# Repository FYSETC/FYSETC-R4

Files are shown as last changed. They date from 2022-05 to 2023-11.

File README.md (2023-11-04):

# FYSETC_R4

## Hardware

All related hardware files are in `hardware` folder in this repository.

## Firmware

FYSETC R4 only support Klipper firmware. All related Klipper firmware files like `printer.cfg` are in `firmware` folder in this repository.

### Klipper Compile options

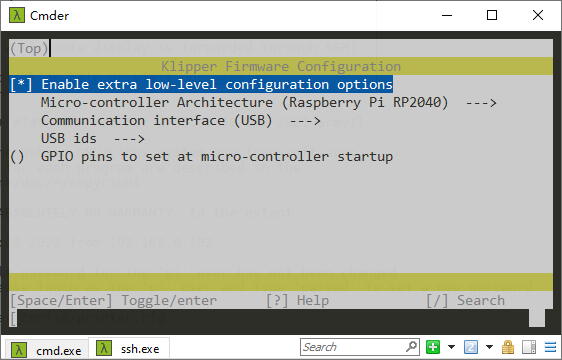
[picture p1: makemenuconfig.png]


### Firmware upload

Step 1: Power on the board

Step 2: Connect R4 to your computer with USBC cable

Step 3: Push an hold `BOOTSEL` button

Step 4: Click `RST` button and release `BOOTSEL` button

Step 5: `RPI-RP2` folder will show up on your computer, copy your built firmware `klipper.uf2` to the folder.

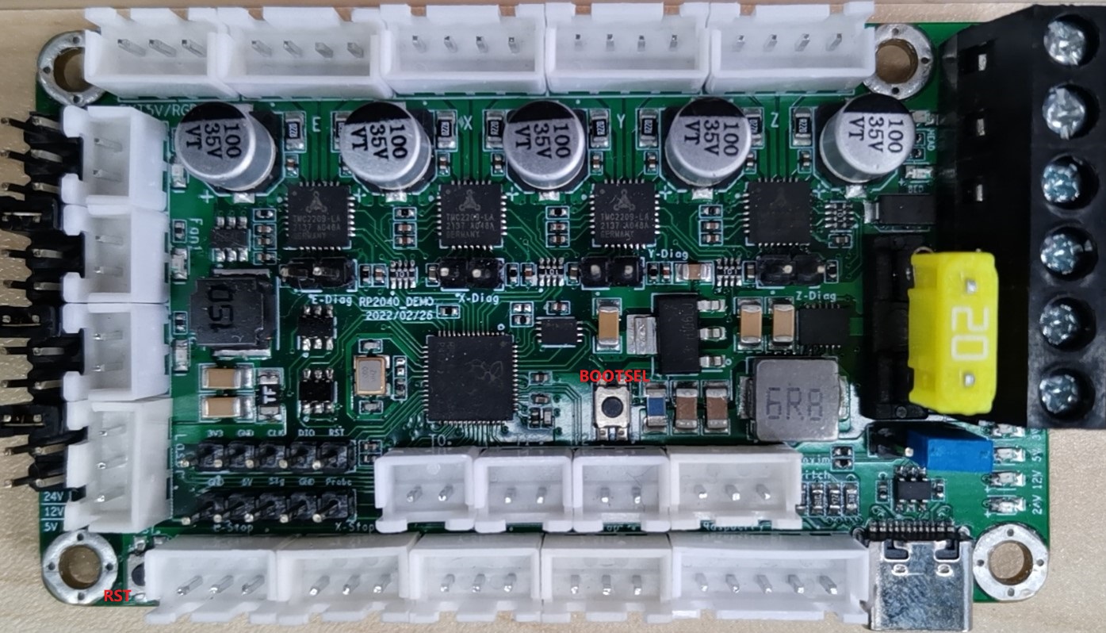
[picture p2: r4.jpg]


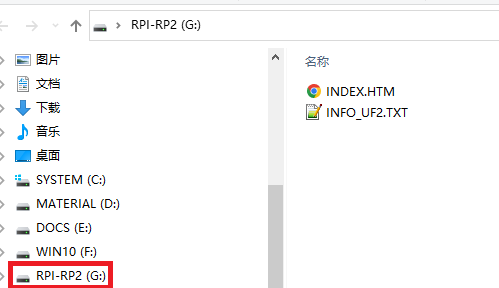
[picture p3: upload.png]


### Configuration

See `printer.cfg` in this repository `firmware` folder.

### Pinout



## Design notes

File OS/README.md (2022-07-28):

# OS

## SAMFi-OS_OrangePi_zero

Before you config the [SAMF-OS_OrangePi_zero](https://github.com/FYSETC/FYSETC-SAMFi-OS). You need an TF card with at least 8G capacity.

### Step 1

Download and flash the OS image with `balenaEtcher` software to your TF card. Insert your flashed TF card to OrangePi-zero and connect Ethernet cable then power on. Find the ip address of OrangePi-zero on your router, host name is `orangepizero`.

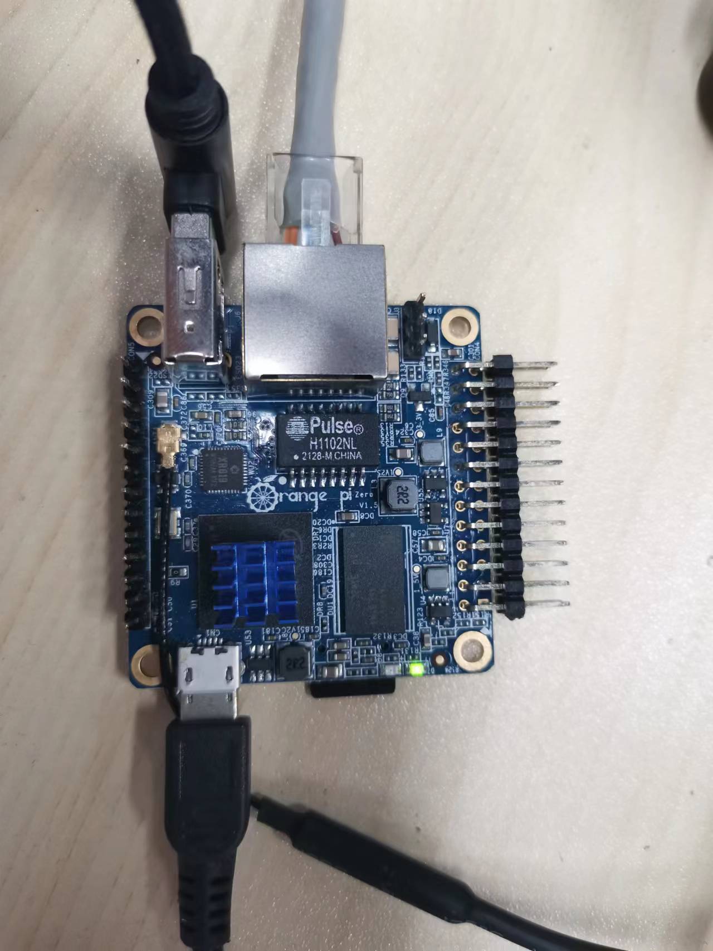
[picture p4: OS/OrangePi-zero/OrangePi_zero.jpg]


### Step 2

You can find the firmware `klipper.uf2` in `OrangePi-zero` folder after you download the github repository. It is also stay in the OS path `firmwares\r4.bin` after you login the OS with SSH.

Original SSH account and password:

```
account: fysetc
password: fysetc123
```

follow the instructions [here](https://github.com/FYSETC/FYSETC-R4#firmware-upload) for firmware uploading. 

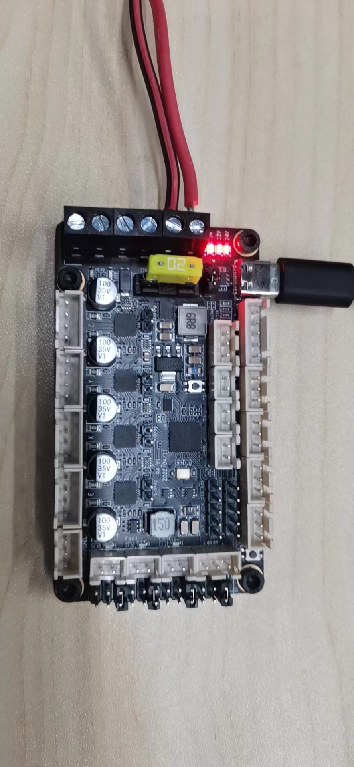
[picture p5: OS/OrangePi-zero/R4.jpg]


### Step 3:

Prepare the `pinter.cfg`, using the command below

```
cp klipper_config/r4.cfg firmwares/printer.cfg
```

You probably need to change `id` by `ls /dev/serial/by-id` command.

I use the generic Klipper config for this example, you need to change it according to your machine. Now visit the webpage with your orangepi-zero IP address. Good to go.

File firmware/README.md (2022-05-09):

# firmware

FYSETC R4 only support Klipper firmware.

## printer.cfg

`printer.cfg` is an example configuration for VORON v0.

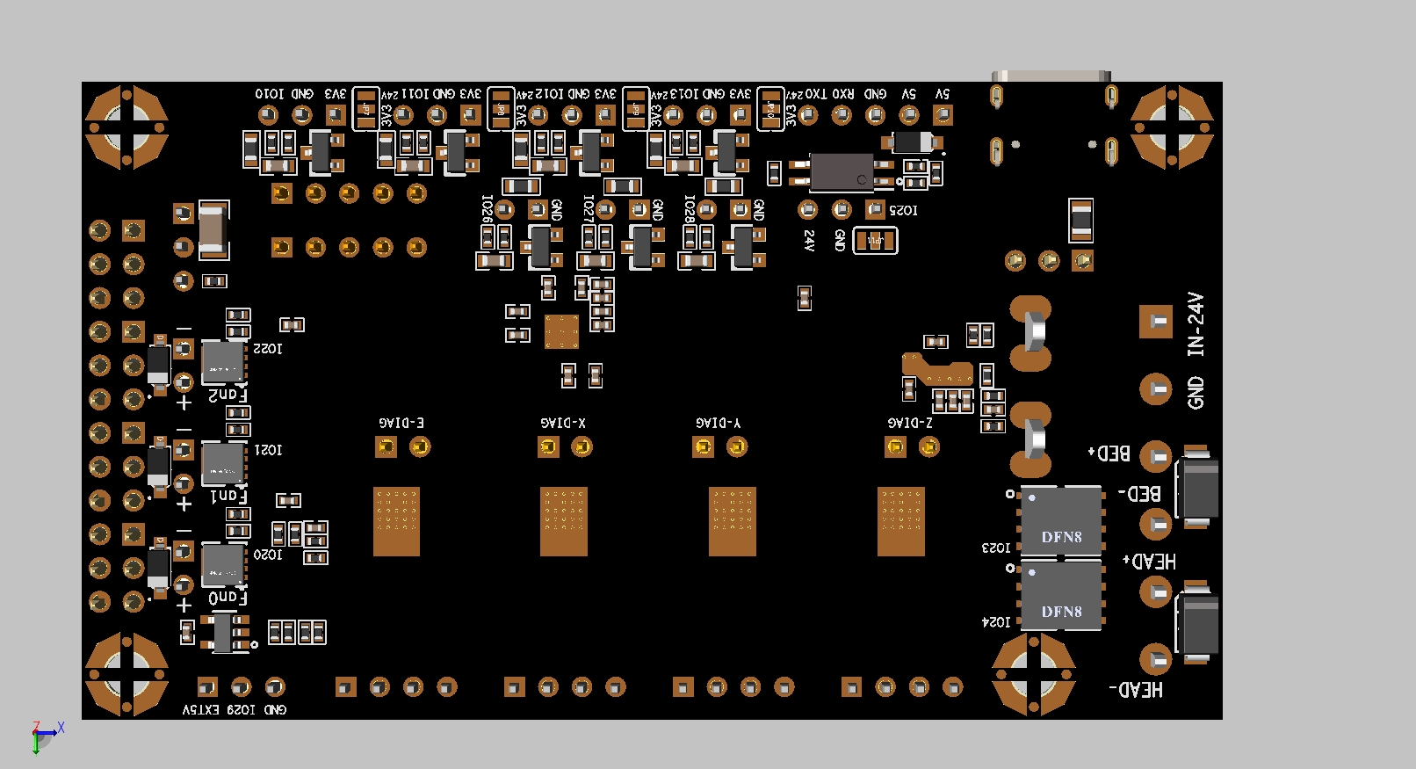
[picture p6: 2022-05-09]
hardware/R4_BOTTOM.jpeg

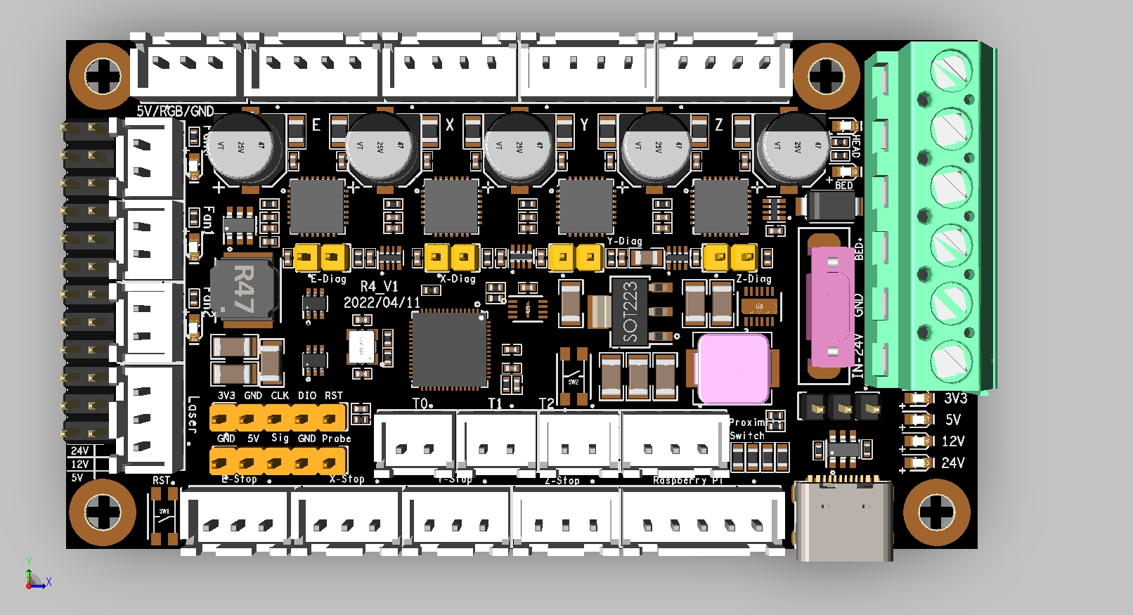
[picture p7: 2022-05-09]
hardware/R4_TOP.jpeg

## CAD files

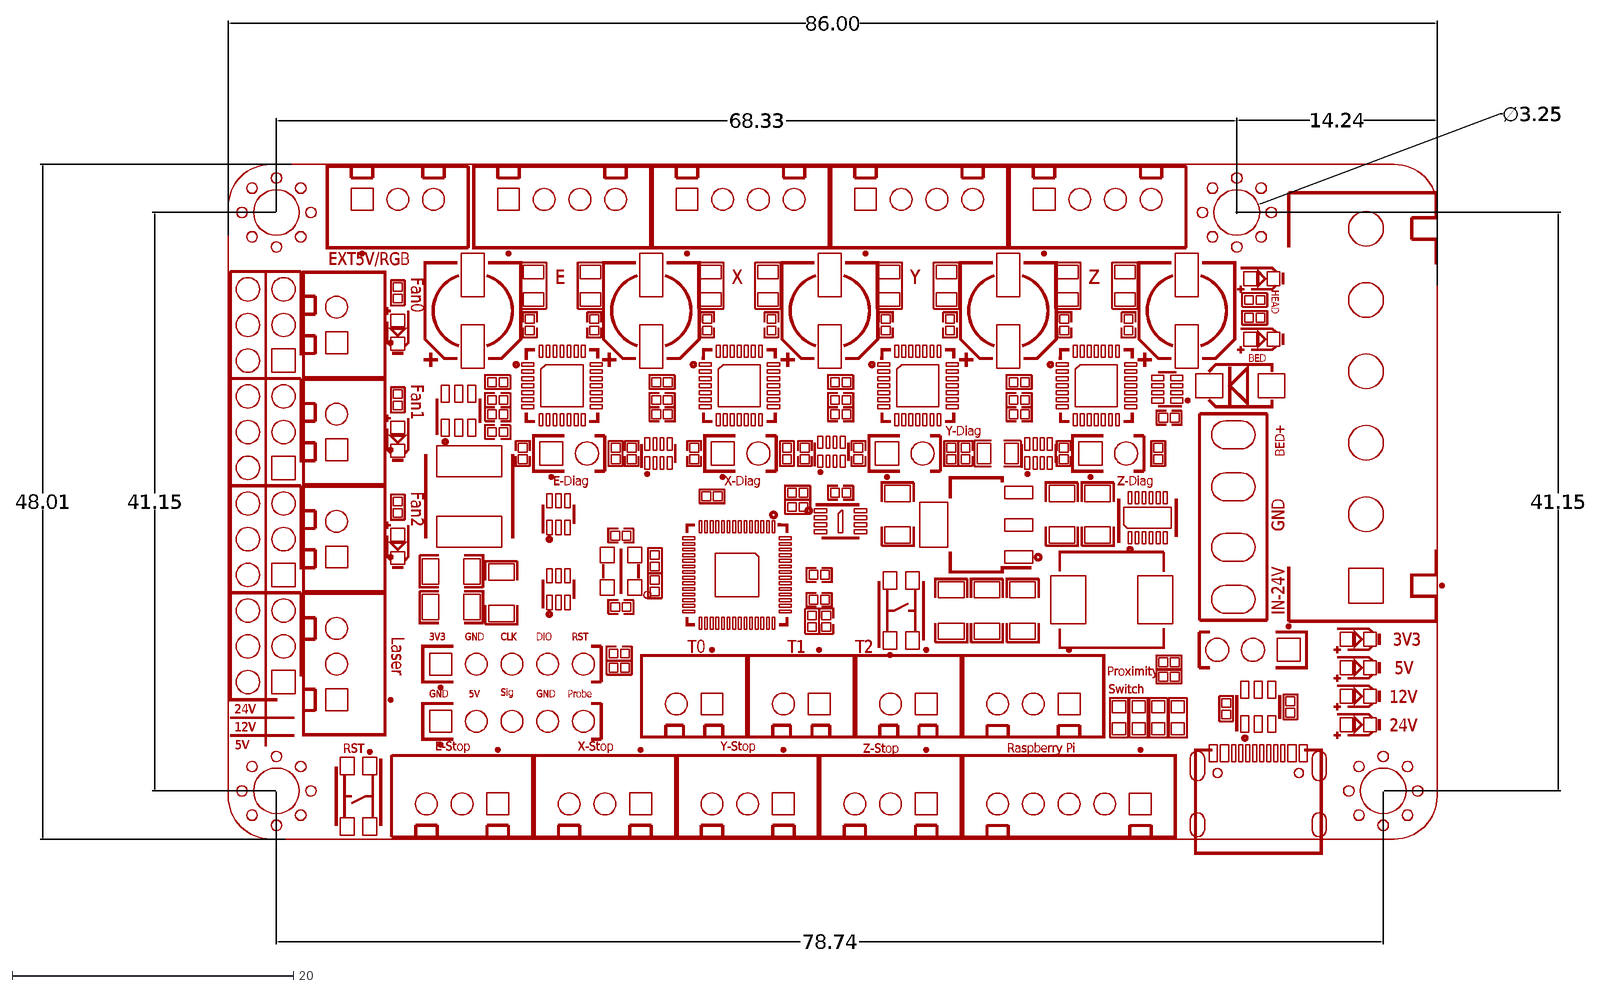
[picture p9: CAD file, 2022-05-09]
hardware/R4_V1_CAD.dxf
Z-Diag
Y-Diag
X-Diag
E-Diag
BED+
GND
IN-24V
Switch
Proximity
Laser
Probe
Sig
5V
BED
HEAD
EXT5V/RGB
12V
24V
RST
T2
T1
T0
DIO
CLK
3V3
Raspberry Pi
Z-Stop
Y-Stop
X-Stop
E-Stop
Fan2
Fan1
Fan0
Z
Y
E
X
14.24
68.33
86.00
41.15
48.01
78.74
∅3.25

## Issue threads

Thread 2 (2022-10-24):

MCU does not start

mmarub, 2022-10-24:
Hello.
I have orange pi lite(armrbian Armbian 22.08.2 Bullseye) and Fysetc R4 with firmware( v0.10.0-613-gebc3b0de).
At startup, the klipper does not see the MCU,  until I press the button RST on MCU.
Why is this happening? the board is inside the printer and it is inconvenient to press the RST button every time.

3DSmitty, 2025-05-04:
Same thing is happening to me.

3DSmitty, 2025-05-05:
I used the flash_nuke method to wipe / reset the pico and then loaded the klipper.uf2 from here and it seems to be working now.

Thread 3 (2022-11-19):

Pinout

TinkerBridget, 2022-11-19:
Hi, can we get a full pinout pic for this board?

I got sent one for free, and I really want to use it, but it doesn't have a full pinout like the spider does so I can't really hook it up without risking killing components or the board.

bistory, 2022-11-26:
👍 I would need it too, especially for laser port and the headers (clk, dio, rst, sig, probe) near the e-stop plug.

dadoblu2000, 2024-12-20:
I have a servo to control where can I connect it on the board?

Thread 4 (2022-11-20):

sensorless homing

freasy, 2022-11-20:
I cant get sensorless homing to work.
What ever configuration i do, it doesnt work. different ^, ~, ! setups, does only change if it does nothing (not moving) or not stopping.
If i change the sense register, it doesnt change the behaviour at all.

mmarub, 2023-01-06:
try to close pins on board, near to XY drivers

zedic, 2023-01-31:
I can **not** get Sensorless Homing to work either.  I have a jumper on X-Diag JP4 and Y-Diag JP5.  I have followed the directions at https://www.klipper3d.org/TMC_Drivers.html#configure-printercfg-for-sensorless-homing

SET_TMC_FIELD STEPPER=stepper_x FIELD=SGTHRS VALUE=255
G28 X0

This causes the stepper to crash into end stop and bang repeatedly. It does not stop. I have tried various homing speeds and SGTHRS values .  No luck.

Here is my config.
```
[stepper_x]
step_pin: gpio3
dir_pin: gpio2
enable_pin: !gpio4
rotation_distance: 40
microsteps: 32
full_steps_per_rotation:
endstop_pin: tmc2209_stepper_x:virtual_endstop
position_endstop: 0
position_max: 235
homing_speed: 20
homing_retract_dist: 0

[tmc2209 stepper_x]
uart_pin: gpio9
tx_pin: gpio8
uart_address: 0
interpolate: False
run_current: 0.8
sense_resistor: 0.110
stealthchop_threshold: 0
diag_pin: ^gpio11
driver_SGTHRS: 255
```

GerogeFu, 2023-02-02:
The point to enable the sensorless feature have 3 key parameters(run_current, hold_current and driver_SGTHRS) need to adjust
```
run_current: 1.2
hold_current: 1
stealthchop_threshold: 999999
diag_pin: ^gpiox
driver_SGTHRS: 20 #100
 ```

It is part of the config

The current need to be big enough to have the motor bump effect, but can't be too big or it won't work too
driver_SGTHRS is related to the load
The three parameter need to have the most effective combination to make sensorless homing work, it take me days to make it work too

And the config homing_retract_dist in [stepper_x] section  need to set to 0

Actually, i don't want to enable this feature, it is not that reliable

zedic, 2023-02-02:
FYI: The Klipper documentation (https://www.klipper3d.org/TMC_Drivers.html) states when setting up sensorless homing: **"Be sure that a hold_current setting is not specified in the TMC driver section of the config."** and they also recommend using "spreadCycle" with microsteps instead of steatlhchop.  But I tried these new settings anyway, and they still did not work for me.  The stepper does not stop.  The end stop pin is never tripped.  I used (diag_pin: ^gpio11) not (diag_pin: ^gpiox).  I'm guessing your using board_pins aliases but that is not shown in the config.

GerogeFu, 2023-02-03:
It is piece of the config, gpiox represent gpio you want to set.

aeresov, 2023-03-24:
I confirm it doesn't work for me either

BluesCoderRepo, 2023-05-11:
Someone solved this problem.(DIY세상 in Korea Kakao Talk Open Chat Room)
The problem is the value of uart_address.
extruder : 0
x: 1
y: 2
z: 3
That's it.

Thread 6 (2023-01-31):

BLTouch not working

zedic, 2023-01-31:
I can not get BLTouch 3.1 working with R4. I have tried two different BLTouch.

I am using these settings:

[stepper_z]
step_pin: gpio19
dir_pin: !gpio18
enable_pin: !gpio17
endstop_pin: probe:z_virtual_endstop  # Use BLTouch

[bltouch]
sensor_pin: gpio13 # White Wire
control_pin: gpio25 # Yellow Wire

The BLTouch does not respond to BLTOUCH_DEBUG COMMAND=pin_up or BLTOUCH_DEBUG COMMAND=pin_down

Attached is a picture of my BLTouch Wiring.
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

zedic, 2023-01-31:
I got the BLTouch working. I put the yellow wire on J32-Pin5 (gpio25) and I moved the signal pin to the z_stop (gpio13).  I checked the schematic and I believe  J32-Pin3 is supposed to be the same as z_stop (gpio13), but it does not seem to work.  I tested J32 pins with a multimeter, and none of those pins have continuity with z_stop.  There seems to be a problem with my board, or bad schematics.

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

I also have not been able to get  Sensorless Homing to work.  This board needs better documentation.

zedic, 2023-01-31:
I got it working using the Z-Stop (J23 - Pin 3.) as shown in the picture.
I believe my issue is related to the circuit.  The Z-stop J23 - Pin 3 circuit has a 10K pull down resistor, but BL-Touch J32 - Pin 3 circuit seems to be connected to RPI GPIO13 in some different way.  When the bltouch is connected to J32 - Pin3 I used the commands BLTOUCH_DEBUG COMMAND=pin_down, BLTOUCH_DEBUG COMMAND=touch_mode, QUERY_PROBE which does **not** result in **tiggered**, but it is tiggered correctly when connected to Z-Stop.  There might be a way to get this working, but I could not figure it out.

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

GerogeFu, 2023-02-02:
I test it on my side it is working, maybe it is related to the config https://www.klipper3d.org/BLTouch.html#bl-touch-v3 , pic is my wiring
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

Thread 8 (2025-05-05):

Klipper Update

3DSmitty, 2025-05-05:
Trying to update klipper firmware on the R4 as the one supplied here is versions behind. Klipper menuconfig it has changed a lot for the RP2040. I tried these options:

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

but it causes the pi to hang and klipper doesn't even start. What should these new options be set to?

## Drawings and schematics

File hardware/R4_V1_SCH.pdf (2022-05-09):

5 | 4 | 3 | 2 | 1

D

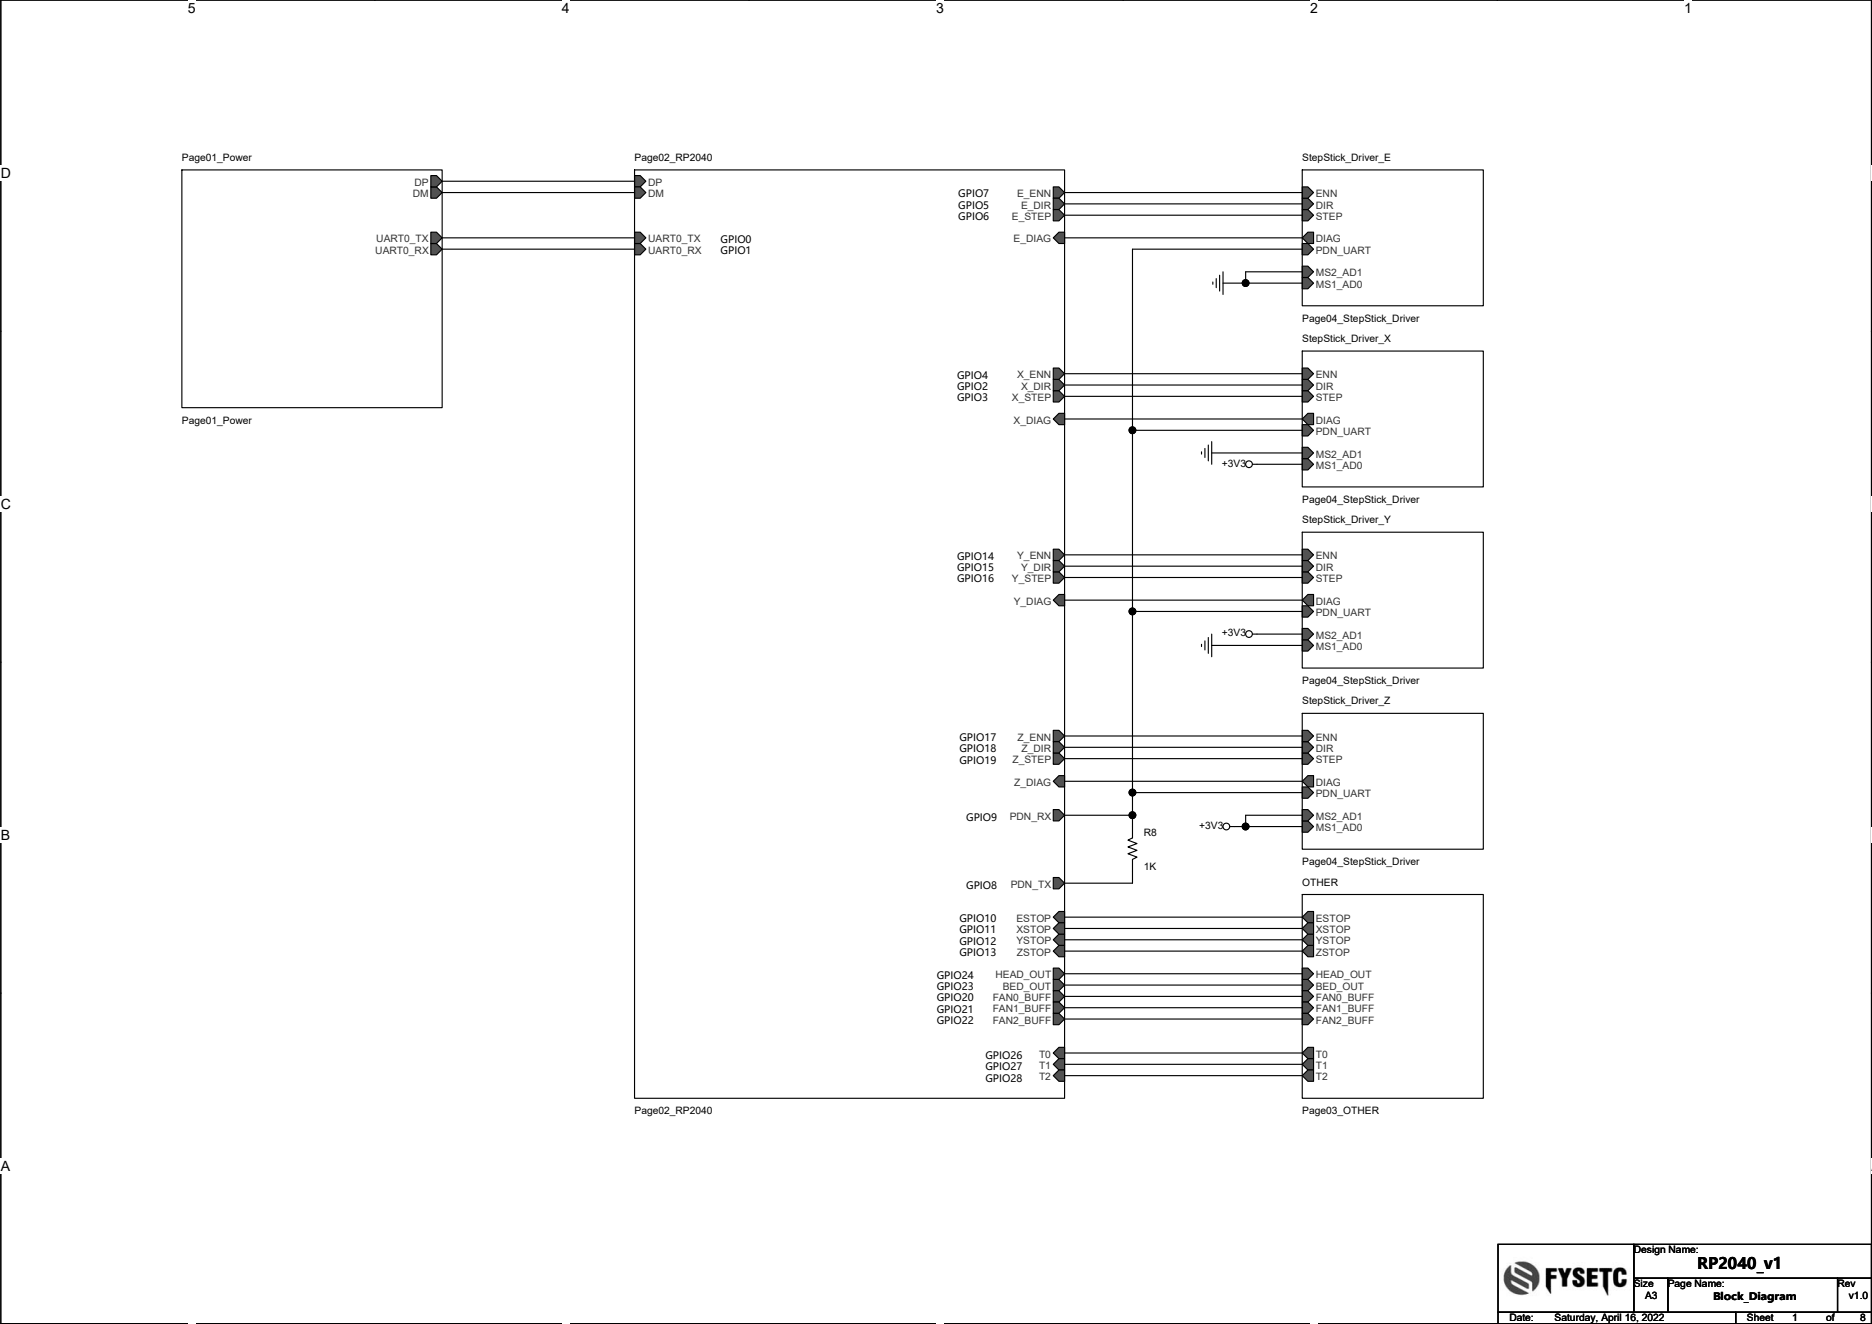
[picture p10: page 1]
GPIO5; GPIO7; GPIO6; GPIO2 GPIO3; GPIO4; GPIO14; GPIO16; GPIO15; GPIO18 GPIO19; GPIO17; GPIO9; GPIO8; GPIO10; GPIO12; GPIO11; GPIO13; GPIO24 GPIO23 GPIO20 GPIO21 GPIO22; GPIO26 GPIO27 GPIO28; GPIO1; GPIO0; OTHER; Page03_OTHER; BED_OUT FAN0_BUFF FAN1_BUFF FAN2_BUFF; HEAD_OUT; ESTOP; YSTOP ZSTOP; XSTOP; StepStick_Driver_E; Page04_StepStick_Driver; DIAG PDN_UART; STEP; DIR; ENN; StepStick_Driver_X; StepStick_Driver_Y; Page01_Power; UART0_RX; UART0_TX; Page02_RP2040; PDN_RX; Z_DIAG; X_DIAG; PDN_TX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

Design Name: RP2040_v1

Size A3 | Page Name: Block_Diagram Block_Diagram Block_Diagram | Rev v1.0

Date: Saturday, April 16, 2022 Saturday, April 16, 2022 Saturday, April 16, 2022 | Sheet 1 1 1 of 8 8 8

D

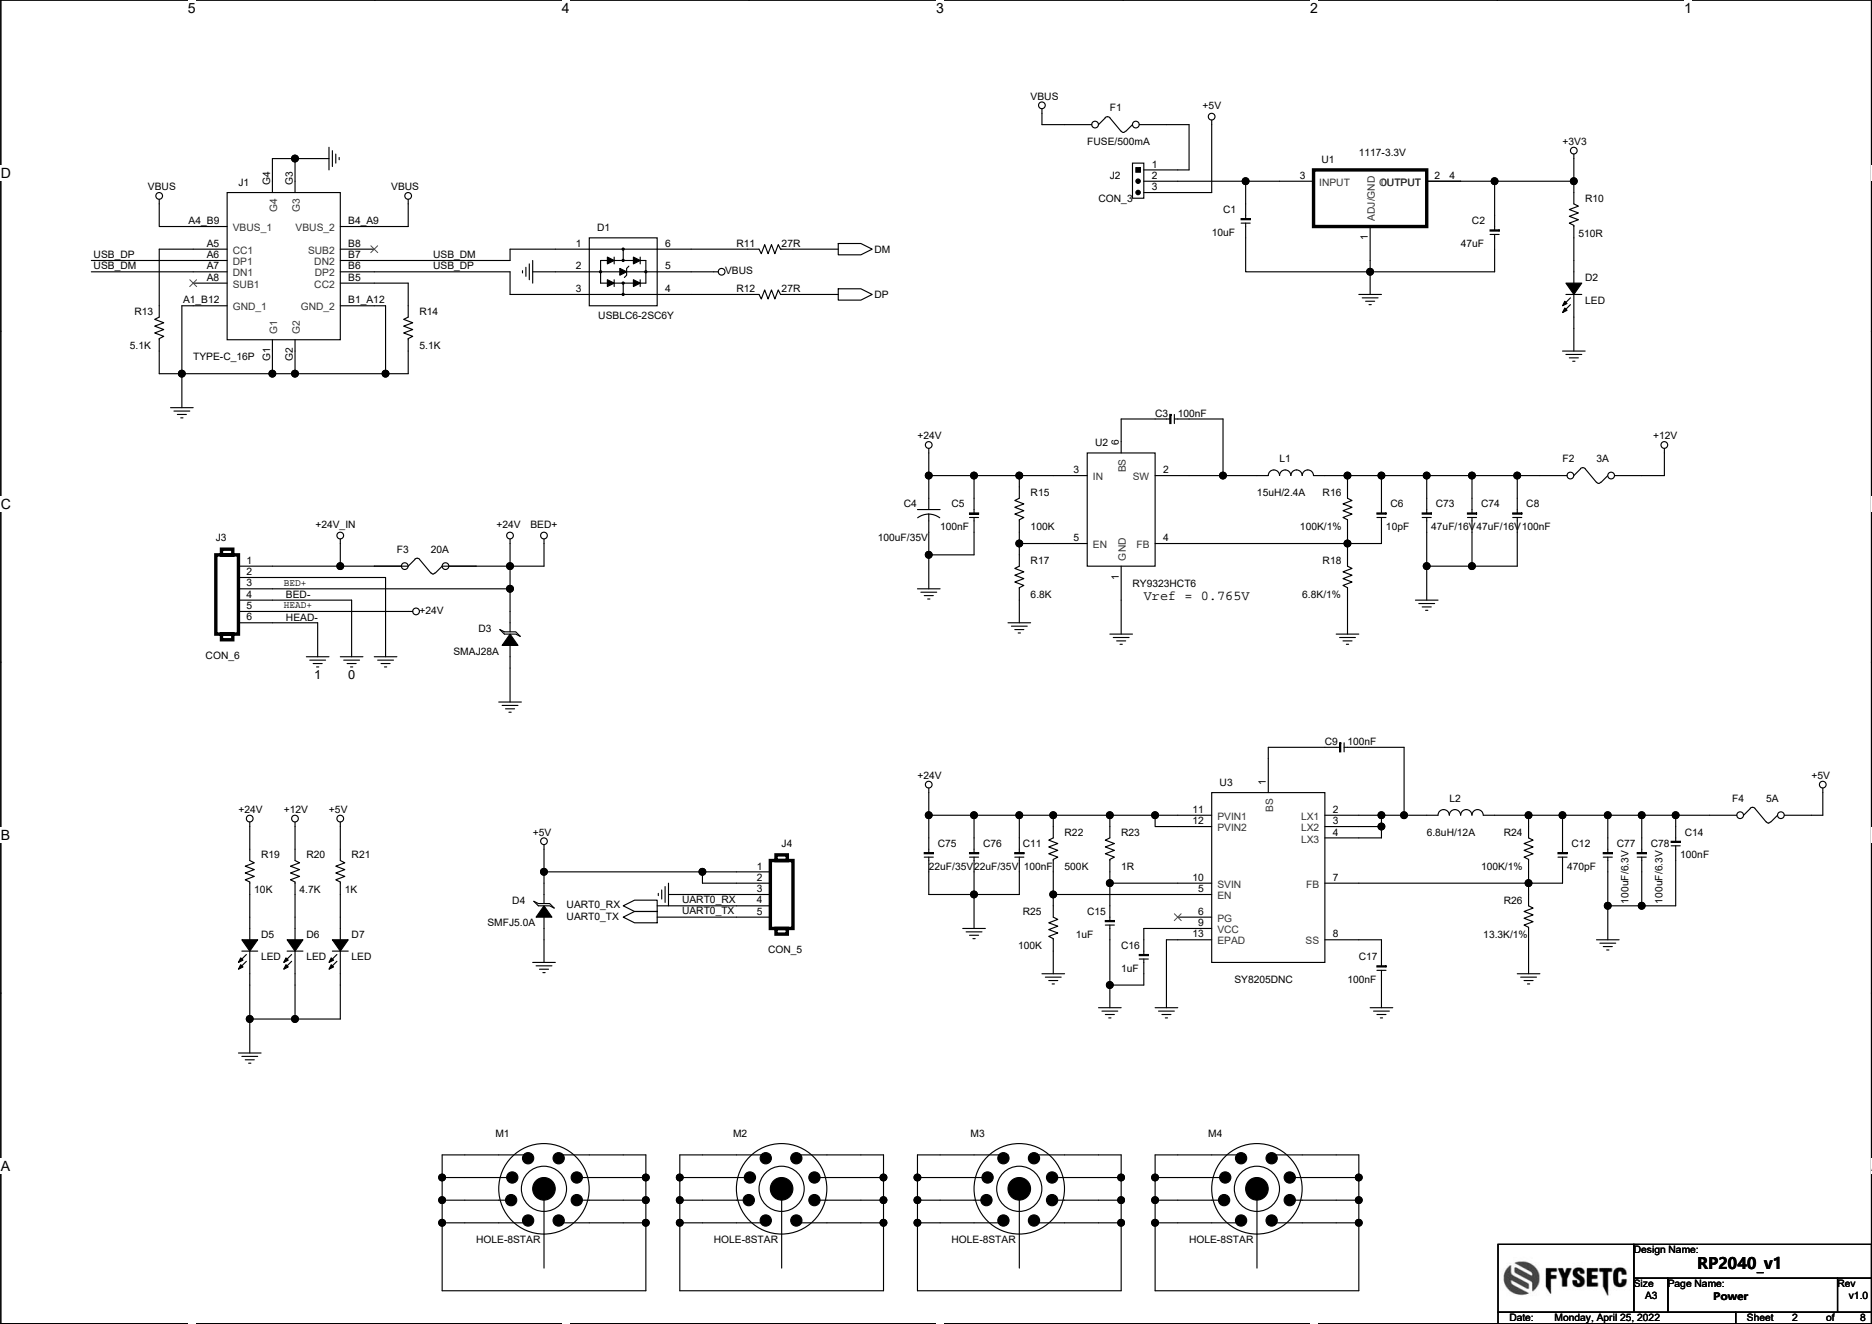
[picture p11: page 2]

PVIN2 12

Power Power Power

Monday, April 25, 2022 Monday, April 25, 2022 Monday, April 25, 2022 | 2 2 2 8 8 8

D

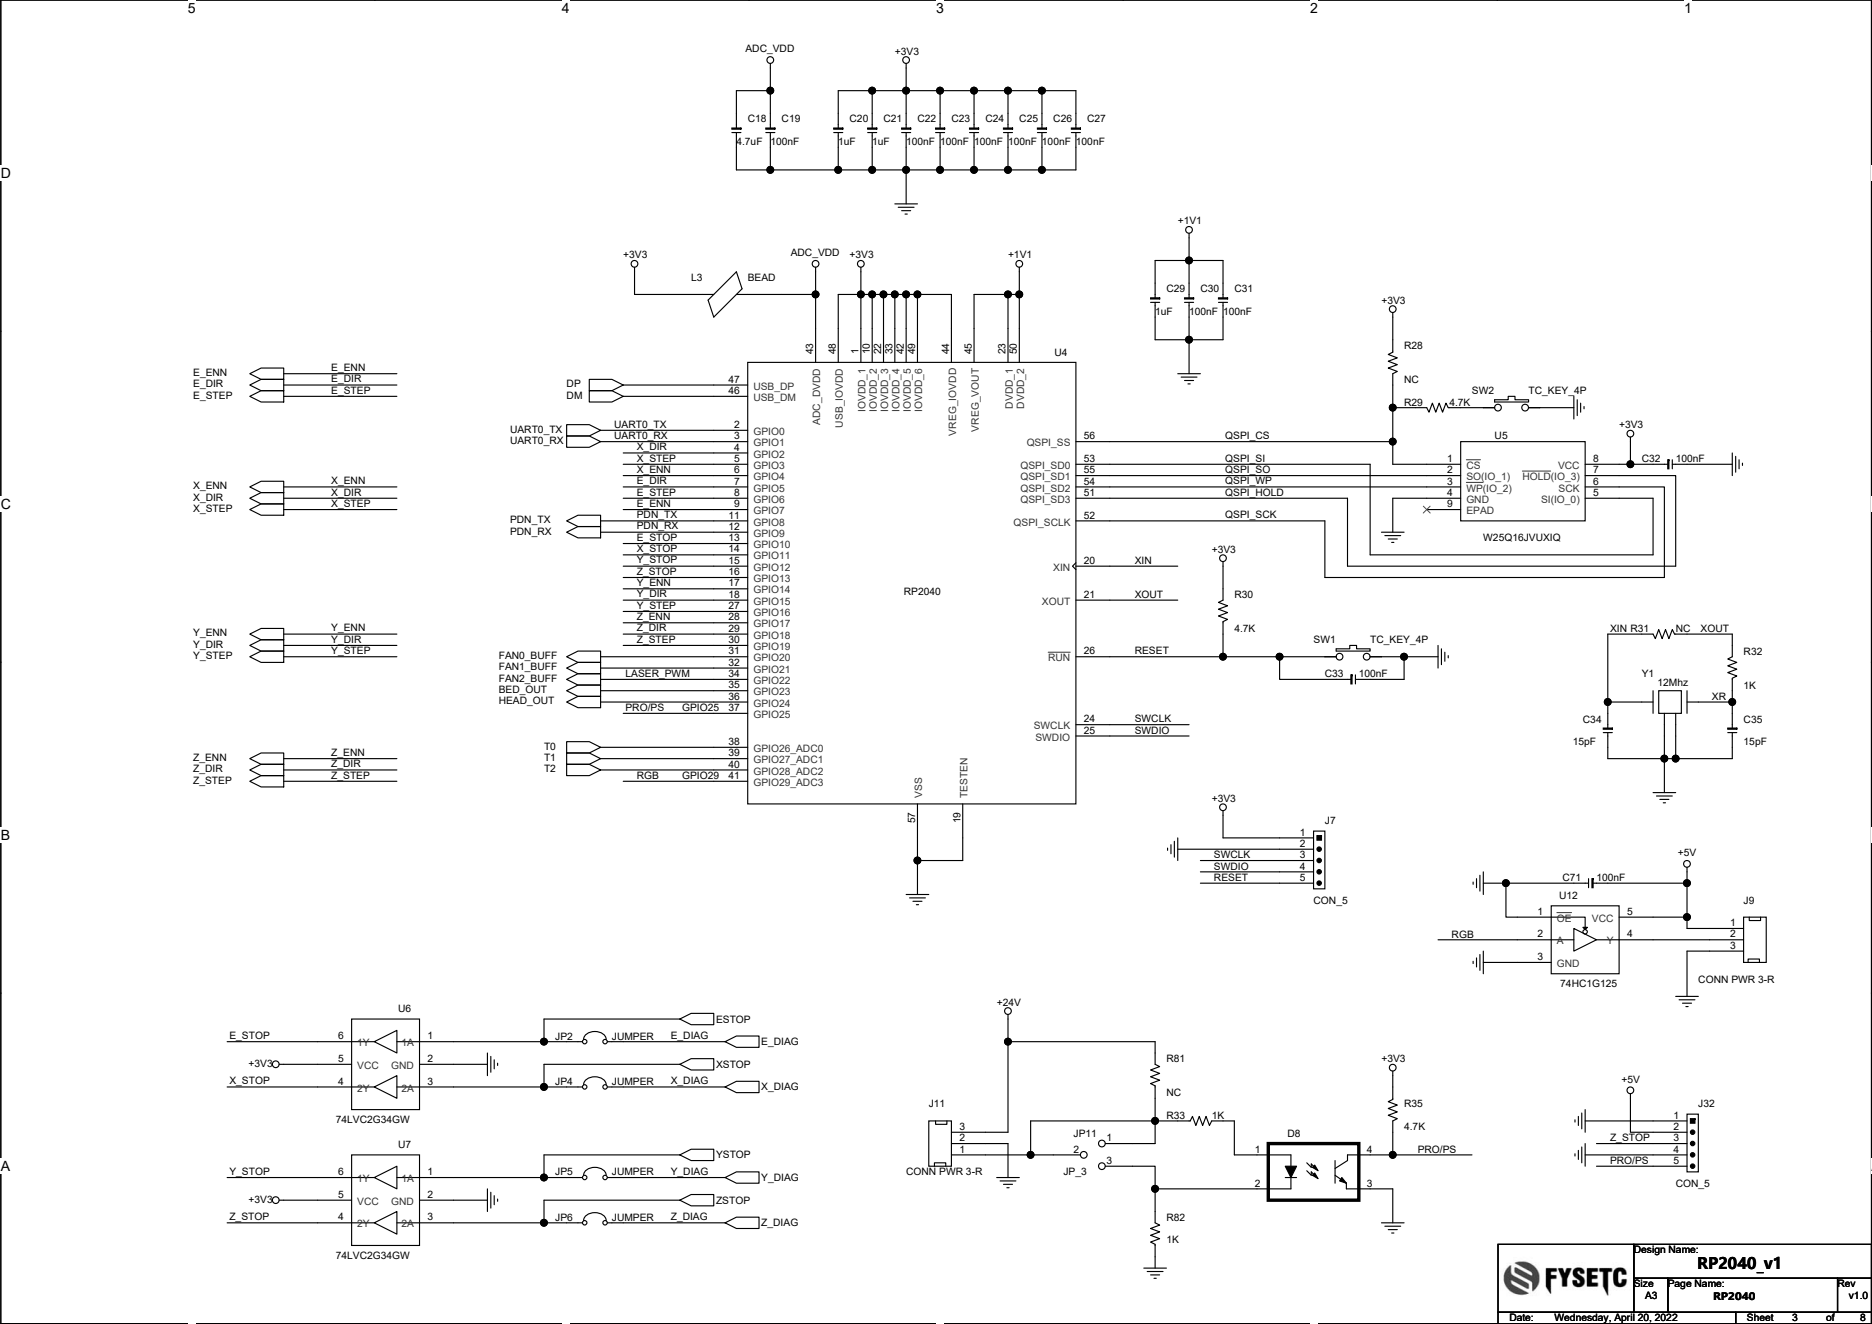
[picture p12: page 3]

QSPI_WP | WP(IO_2) 3
QSPI_HOLD

Wednesday, April 20, 2022 Wednesday, April 20, 2022 Wednesday, April 20, 2022 | 3 3 3 8 8 8

D

# Fan

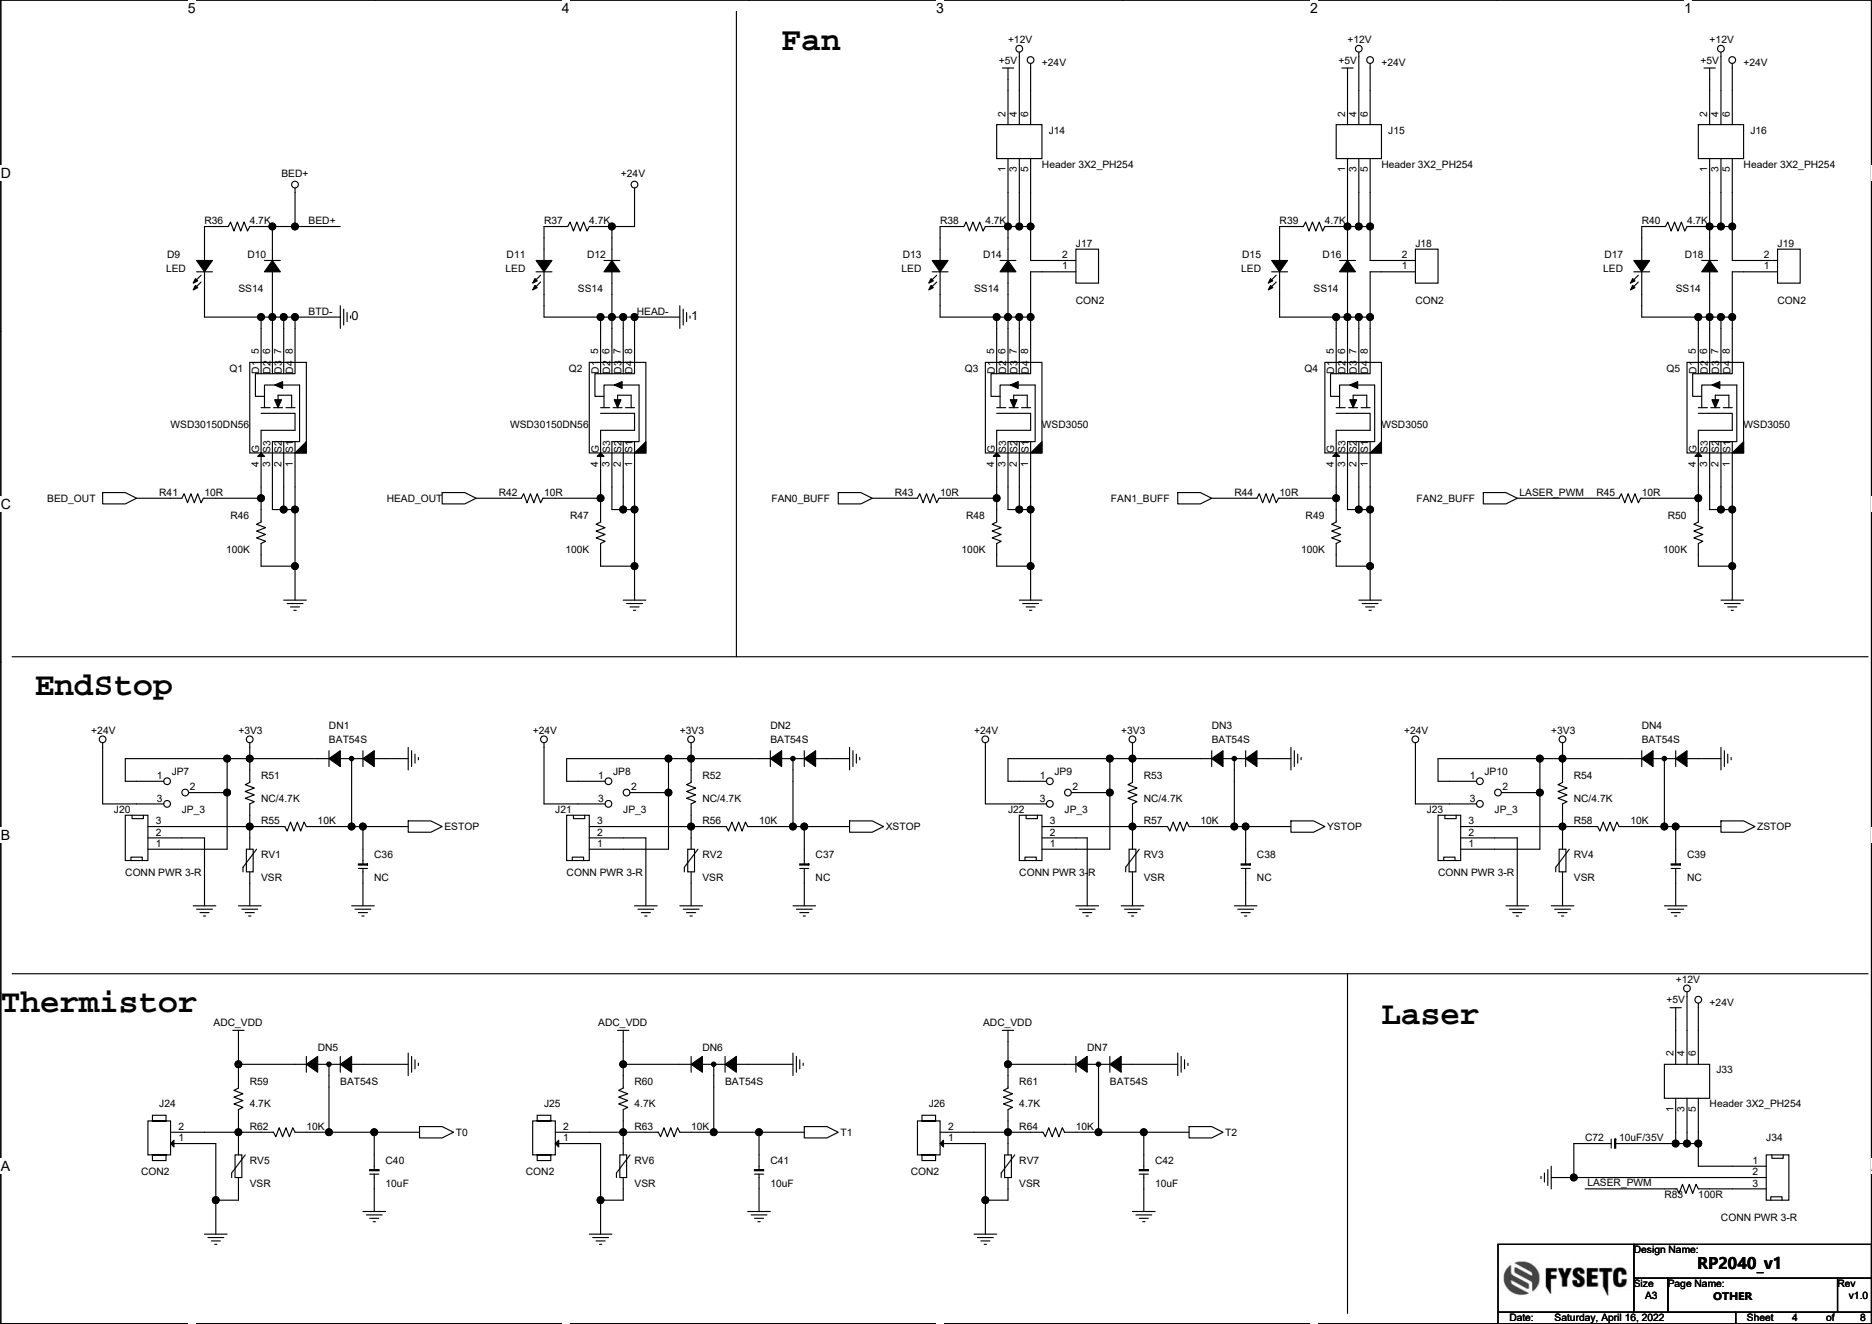
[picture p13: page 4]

OTHER OTHER OTHER

Saturday, April 16, 2022 Saturday, April 16, 2022 Saturday, April 16, 2022 | 4 4 4 8 8 8

D

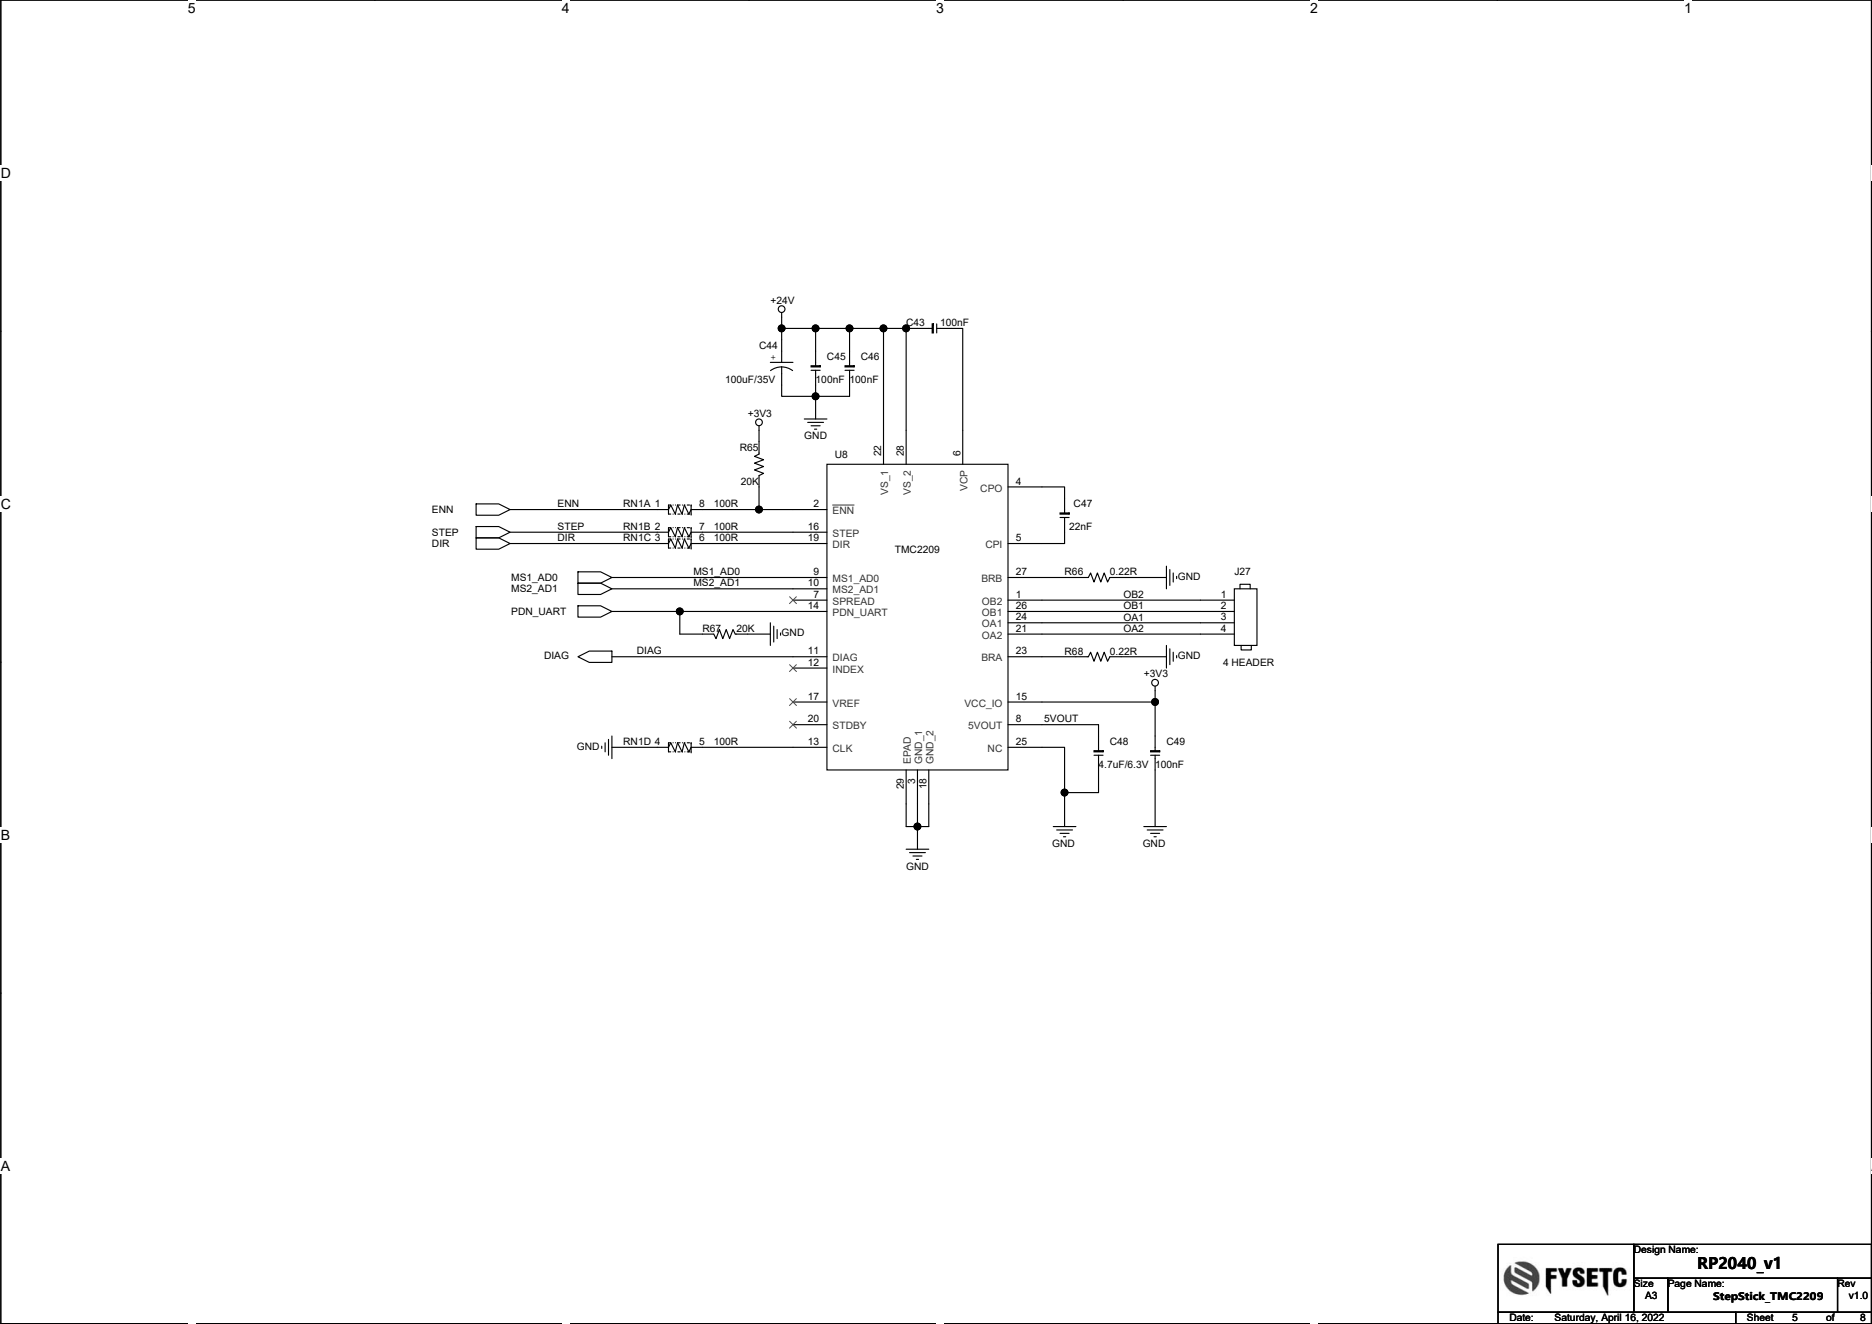
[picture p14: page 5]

StepStick_TMC2209

Saturday, April 16, 2022 Saturday, April 16, 2022 Saturday, April 16, 2022 | 5 5 5 8 8 8

D

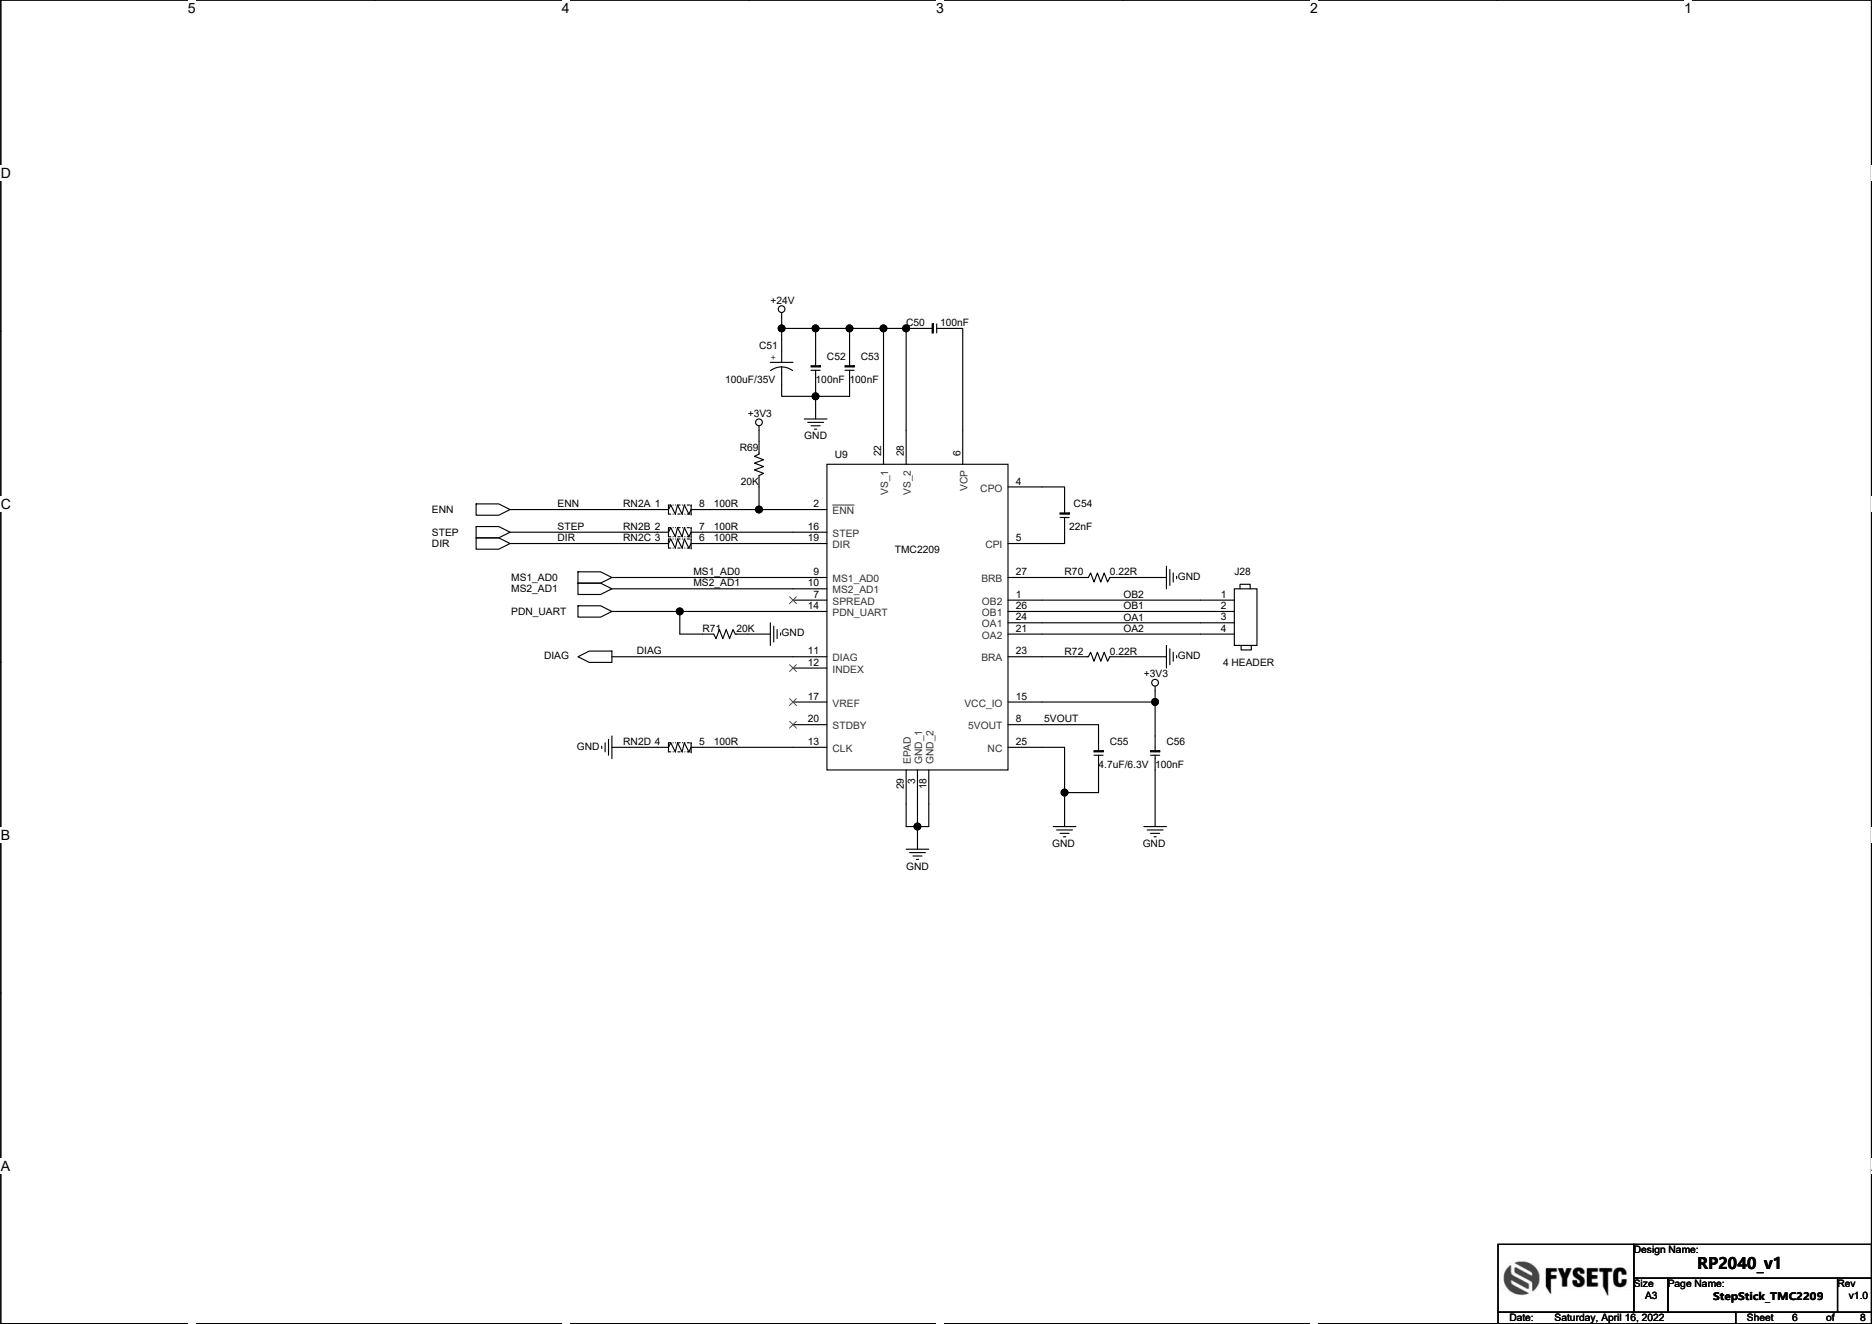
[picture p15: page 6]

D

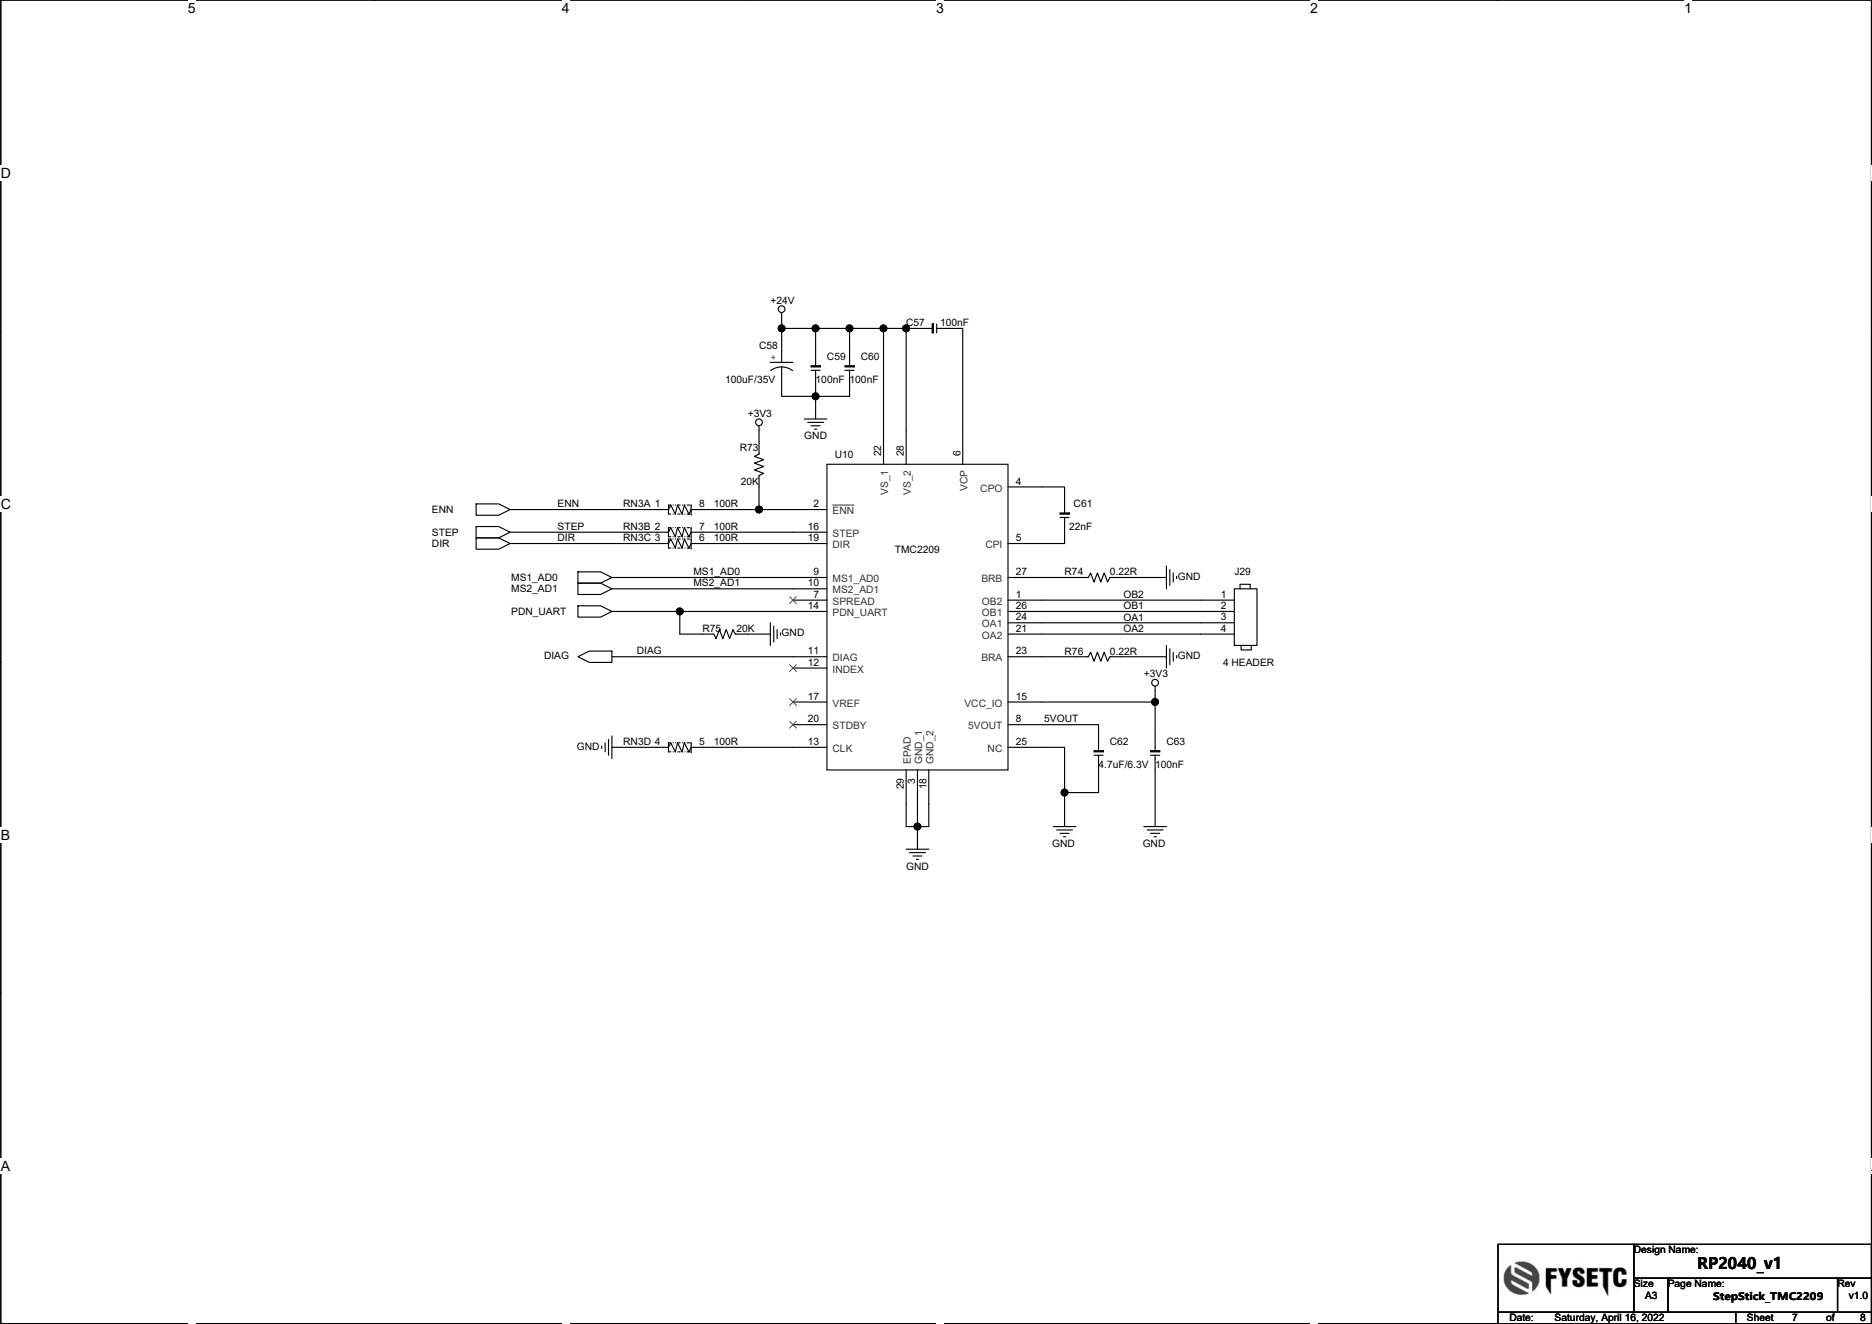
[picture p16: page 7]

D

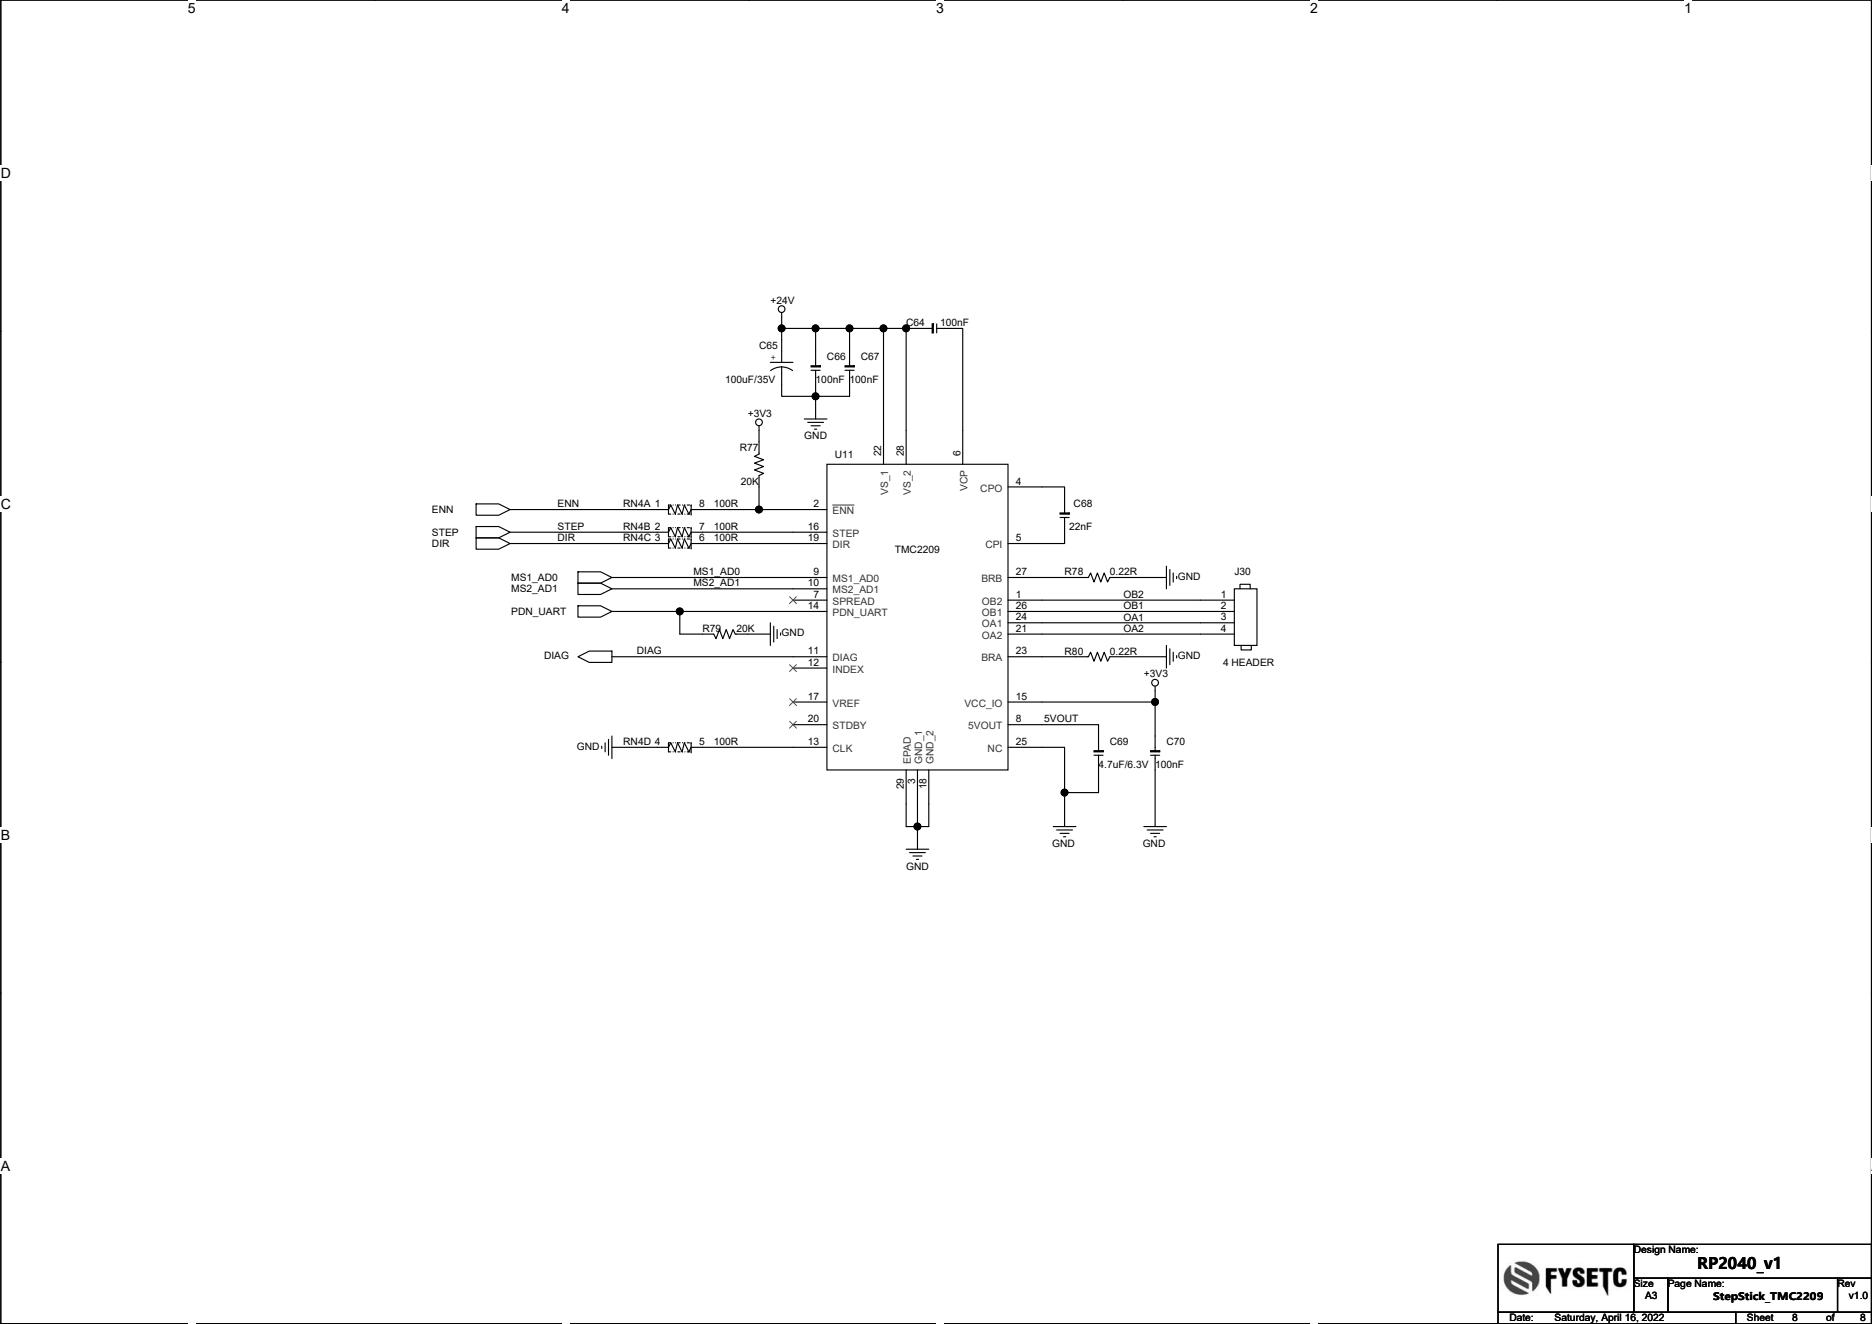
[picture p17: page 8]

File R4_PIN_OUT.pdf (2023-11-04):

# R4_V1.0_Pin_Out

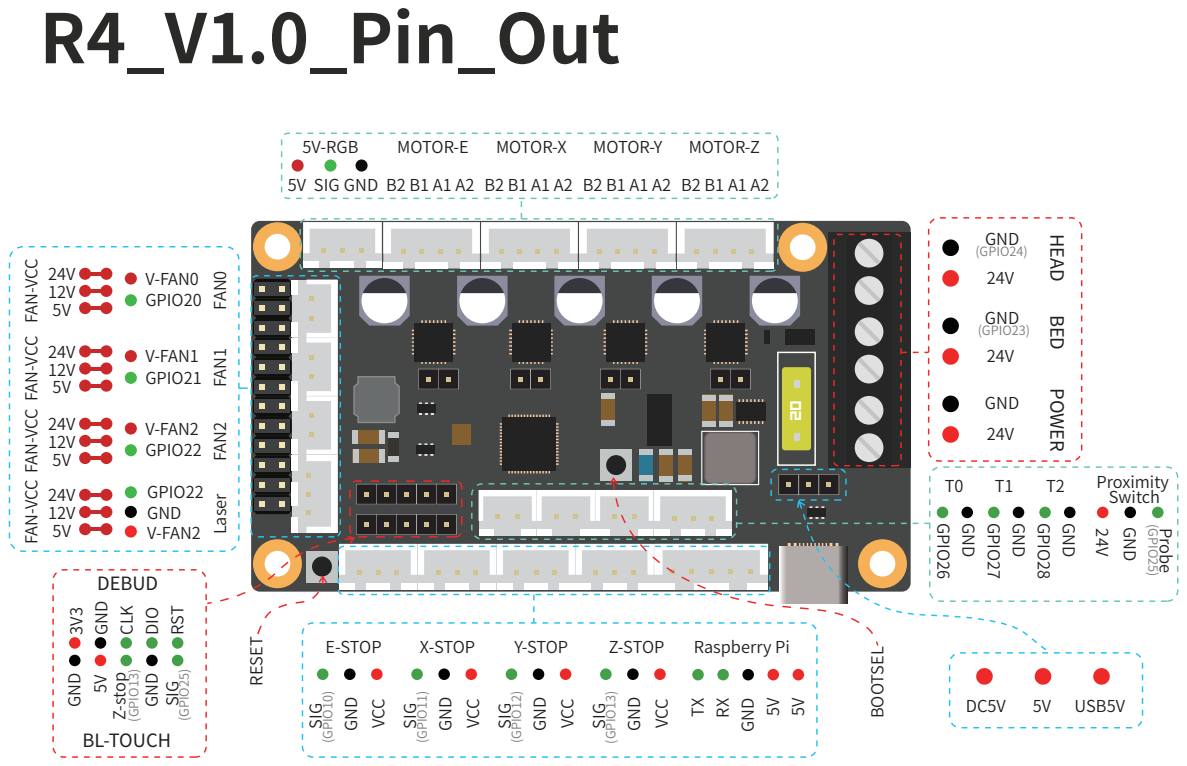
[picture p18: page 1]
5V SIG GND; 5V-RGB; GND 24V; (GPIO24) GND 24V; (GPIO23); GPIO26; GND; GPIO27; GPIO28 GND; (GPIO25) Probe; T0 T1 T2 Proximity Switch; BOOTSEL; RESET; USB5V; Raspberry Pi GNDTXRX5V; (GPIO13); (GPIO25); 5V GND; Z-stop; SIG; CLK DIO; DEBUD; BL-TOUCH; V-FAN0; GPIO20; FAN-VCC; FAN0; V-FAN1; GPIO21; FAN1; V-FAN2; GPIO22; FAN2; Laser

MOTOR-E MOTOR-X MOTOR-Y MOTOR-Z

HEAD BED POWER

RST
E-STOP GND VCC (GPIO¹⁰⁾ SIG

X-STOP GND VCC (GPIO¹¹⁾ SIG

Y-STOPGND VCC (GPIO¹²⁾ SIG

Z-STOP GND VCC (GPIO¹³⁾ SIG

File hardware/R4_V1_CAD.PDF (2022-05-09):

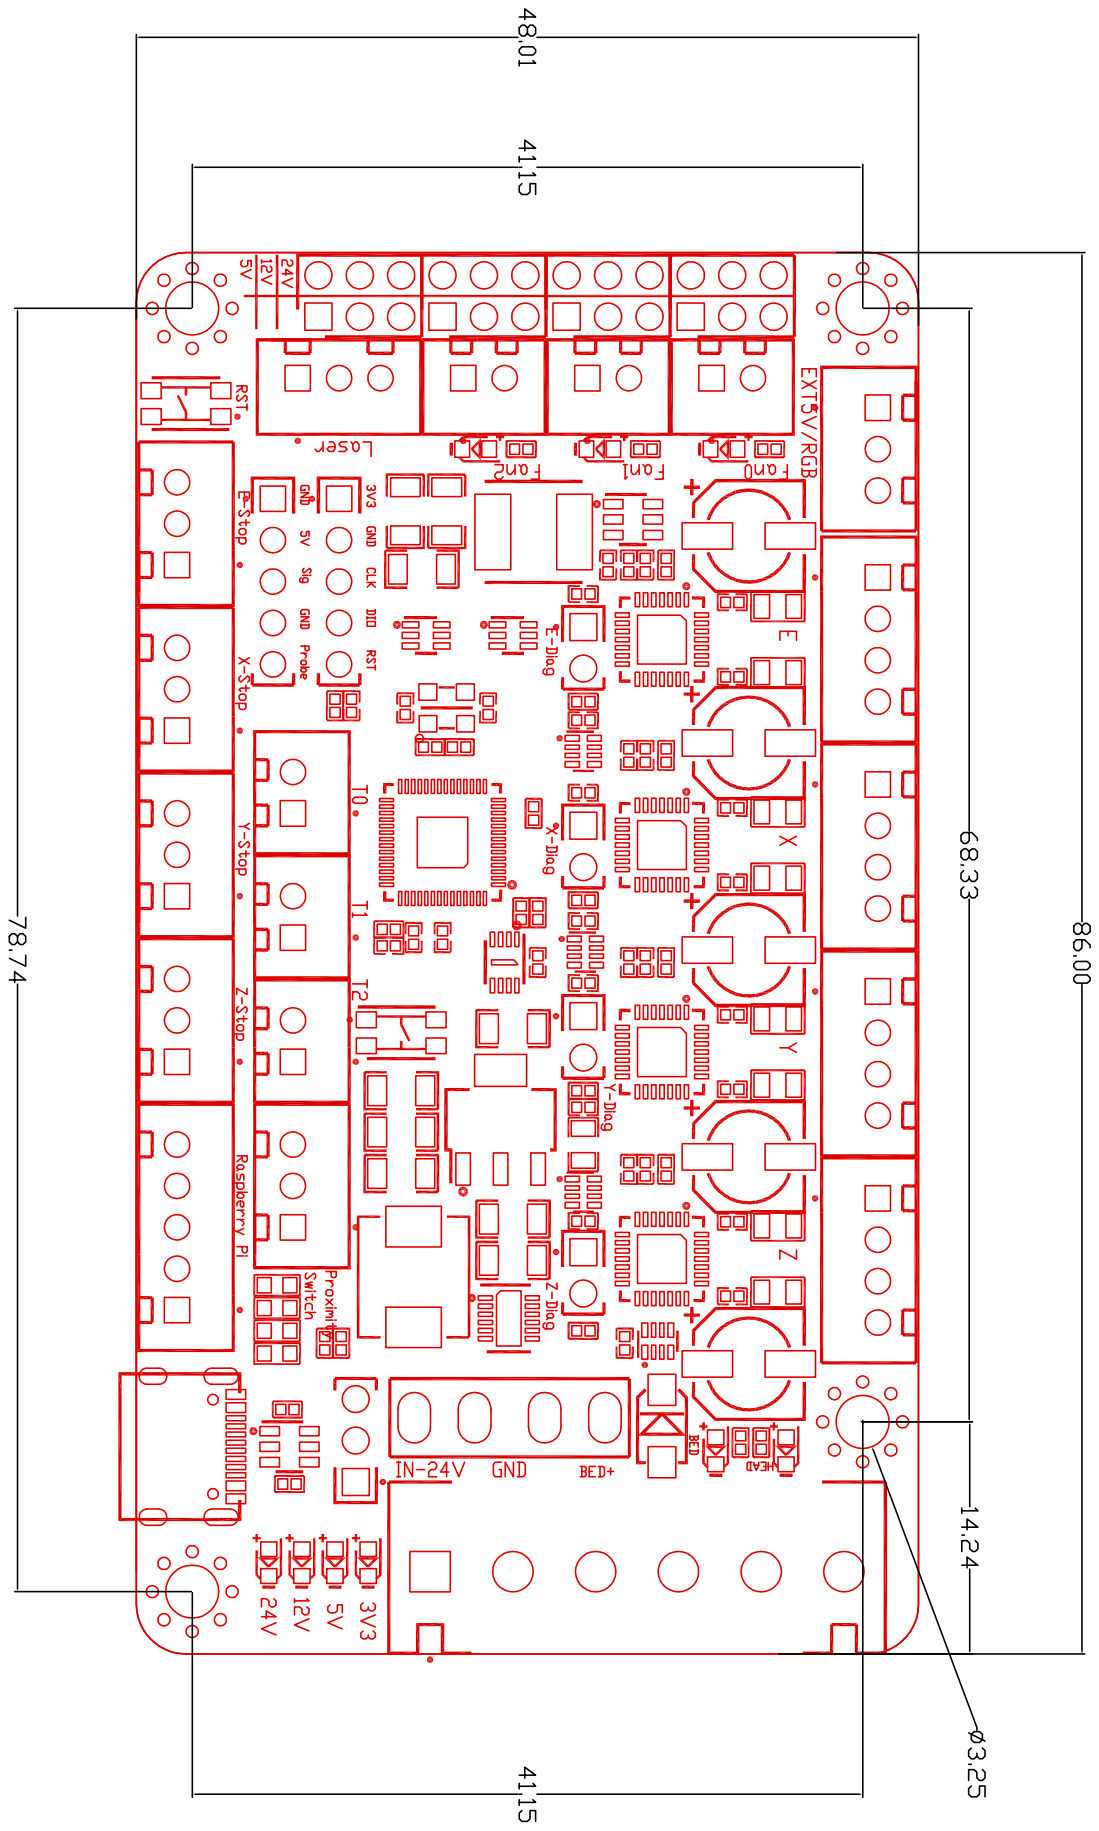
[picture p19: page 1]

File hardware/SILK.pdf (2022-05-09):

# ART FILM - adt

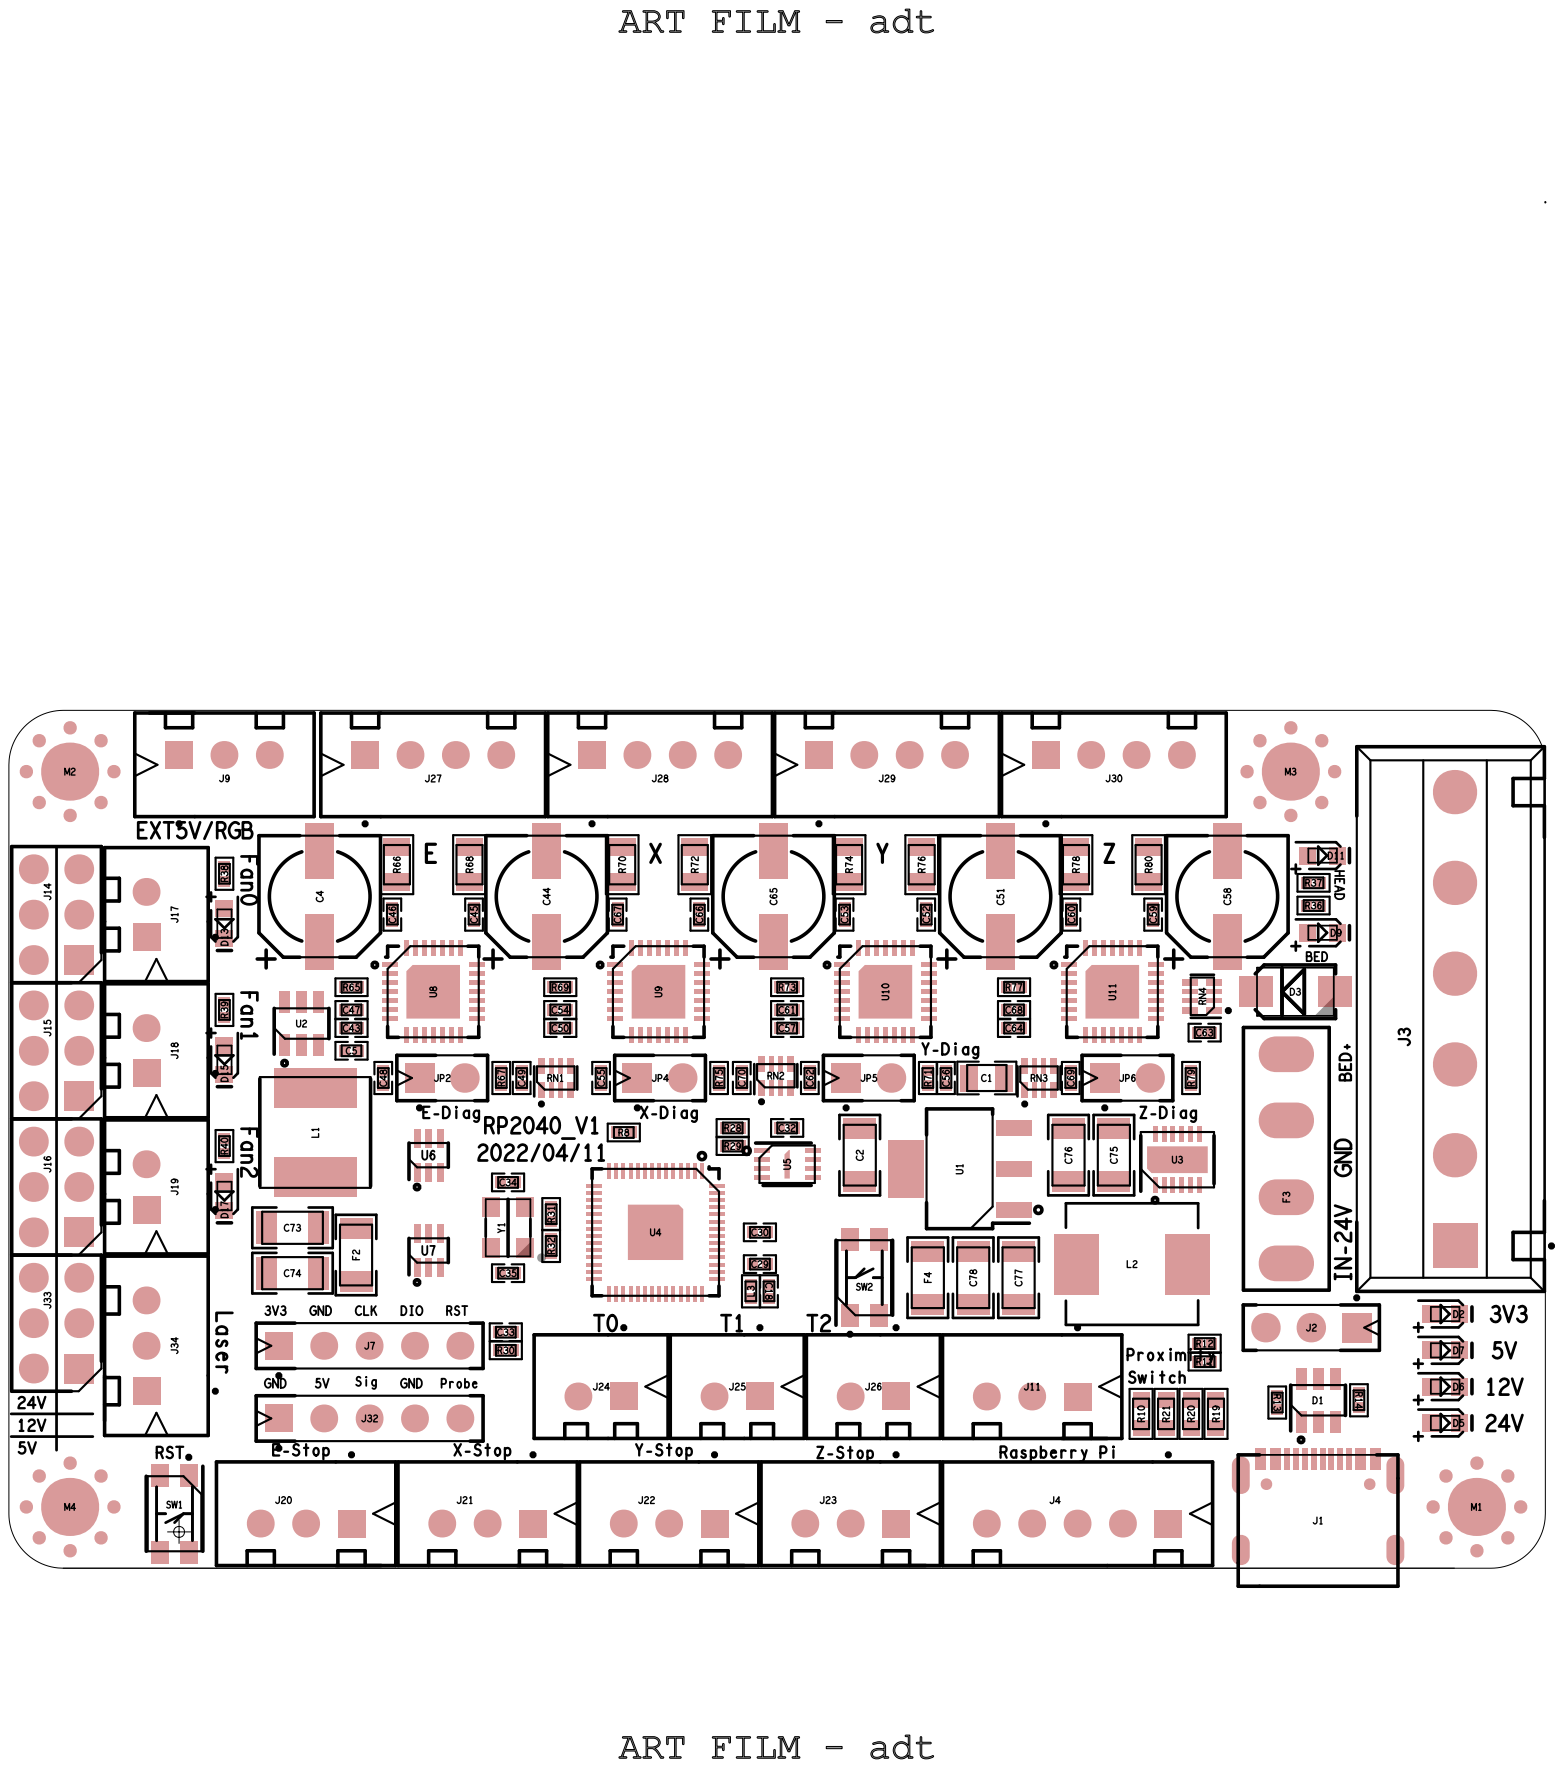
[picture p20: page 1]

# ART FILM - adb

# IO29 EXT5V

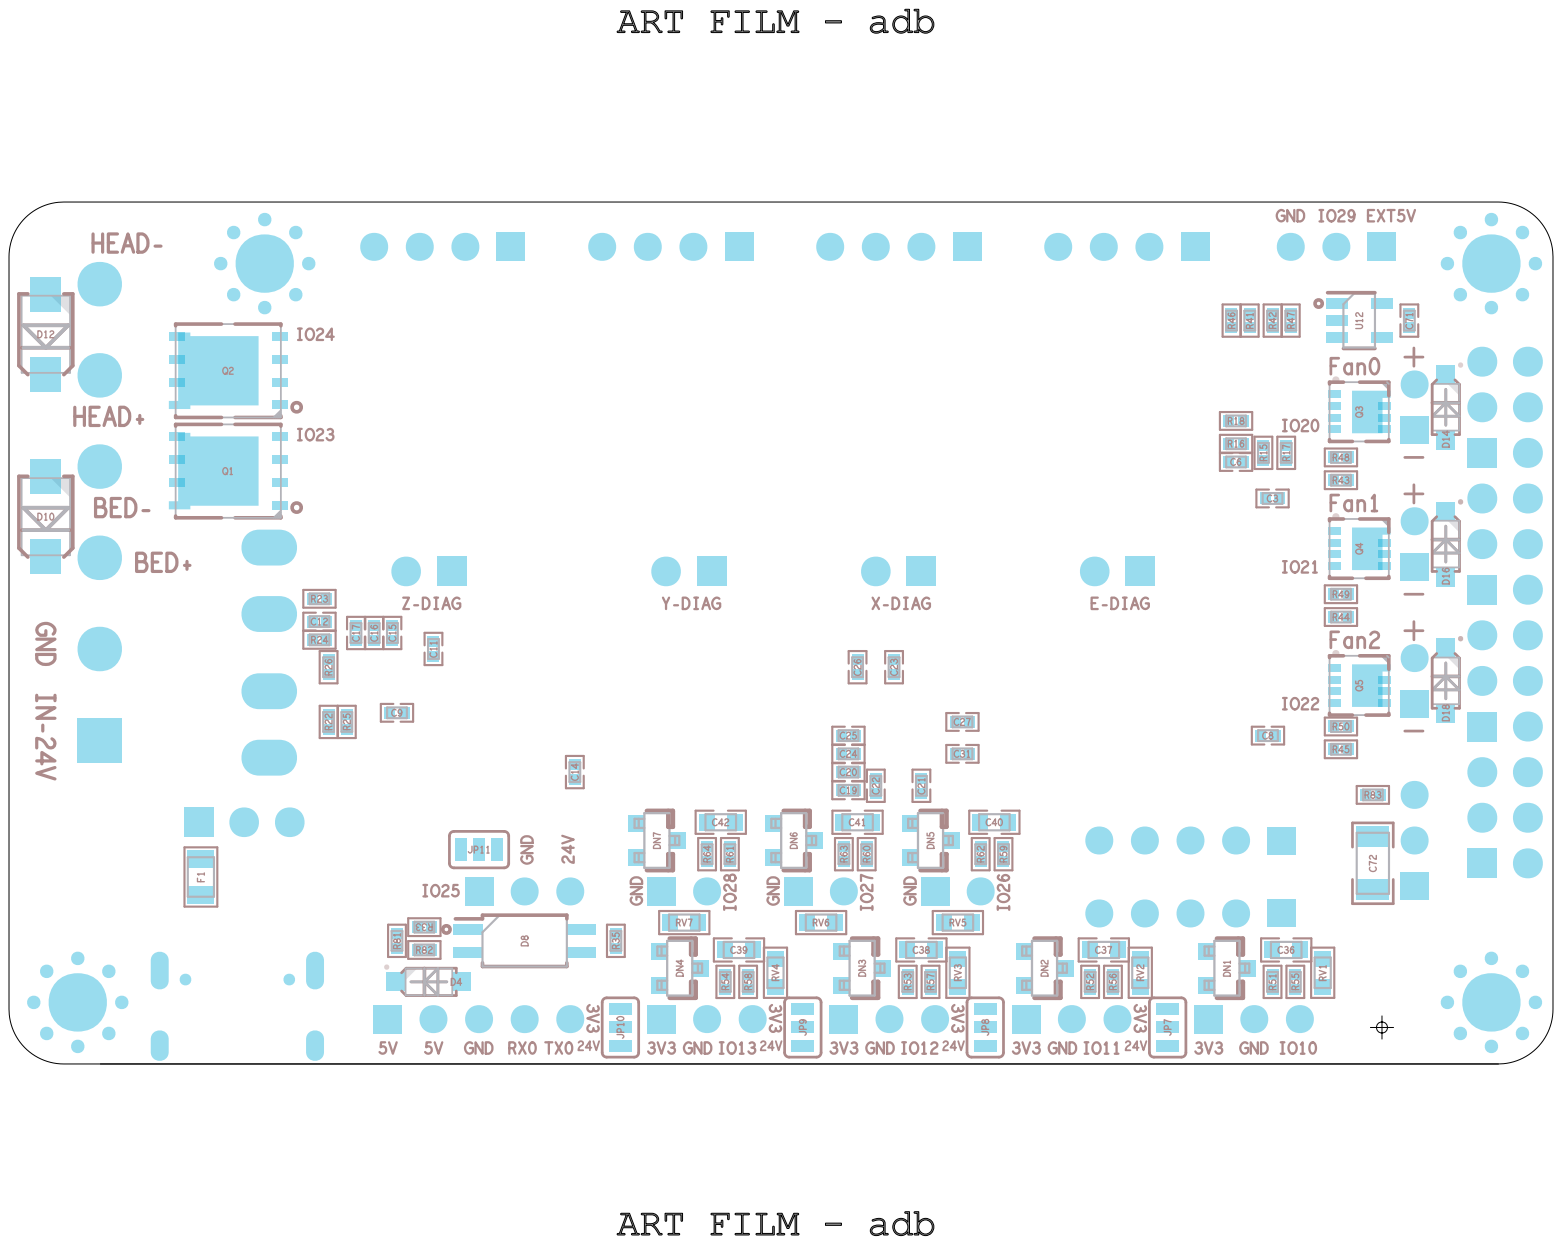
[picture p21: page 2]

# ART FILM - silktop


# ART FILM - silkbotm

# IO29 EXT5V


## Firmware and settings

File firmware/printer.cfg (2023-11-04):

[include mainsail.cfg]

[mcu]
##	Obtain mcu value by "ls -l /dev/serial/by-id/" 
serial: /dev/serial/by-id/usb-Klipper_rp2040_E16044B34B343525-if00
#serial: /dev/ttyAMA0
restart_method: command

[stepper_x]
step_pin: gpio3
dir_pin: !gpio2
enable_pin: !gpio4
rotation_distance: 40
microsteps: 16
endstop_pin: ^!gpio11
# endstop_pin: tmc2209_stepper_x:virtual_endstop
# 
position_endstop: 120
position_max: 120
homing_speed: 50
homing_retract_dist: 5
homing_positive_dir: true

[tmc2209 stepper_x]
uart_pin: gpio9
tx_pin: gpio8
# MS2/AD1=0,MS1/AD0=1
uart_address: 1   
interpolate: True
run_current: 0.8
hold_current: 0.6
sense_resistor: 0.220
stealthchop_threshold: 999999
# diag_pin: ^gpio11
# driver_SGTHRS: 100

[stepper_y]
step_pin: gpio16
dir_pin: !gpio15
enable_pin: !gpio14
rotation_distance: 40
microsteps: 16
endstop_pin: ^!gpio12
# endstop_pin: tmc2209_stepper_y:virtual_endstop
position_endstop: 120
position_max: 120
homing_speed: 50
homing_retract_dist: 5

[tmc2209 stepper_y]
uart_pin: gpio9
tx_pin: gpio8
# MS2/AD1=1,MS1/AD0=0
uart_address: 2
run_current: 0.8
hold_current: 0.6
sense_resistor: 0.220
stealthchop_threshold: 999999
#diag_pin: ^gpio12
#driver_SGTHRS: 100

[stepper_z]
step_pin: gpio19
dir_pin: !gpio18
enable_pin: !gpio17
rotation_distance: 8 #for T8x8 lead screw
microsteps: 16
rotation_distance: 8
endstop_pin: ^!gpio13
position_endstop: 0
#endstop_pin: probe:z_virtual_endstop
position_min: -1.0
position_max: 250
homing_speed: 12
second_homing_speed: 3.0
homing_retract_dist: 3.0

[tmc2209 stepper_z]
uart_pin: gpio9
tx_pin: gpio8
# MS2/AD1=1,MS1/AD0=1
uart_address: 3
run_current: 0.580
hold_current: 0.500
sense_resistor: 0.220
stealthchop_threshold: 999999

[extruder]
step_pin: gpio6
dir_pin: !gpio5
enable_pin: !gpio7
full_steps_per_rotation: 200    # 1.8 degree motor
rotation_distance: 22.23        # See calibrating rotation_distance on extruders doc
gear_ratio: 50:10               # For Mini Afterburner
microsteps: 16
rotation_distance: 33.500
nozzle_diameter: 0.4
filament_diameter: 1.75
heater_pin: gpio24
sensor_type: EPCOS 100K B57560G104F
sensor_pin: gpio28
control: pid
pid_Kp: 22.2
pid_Ki: 1.08
pid_Kd: 114
min_temp: 0
max_temp: 300
min_extrude_temp: 170
max_extrude_only_distance: 780.0
max_extrude_cross_section:2
pressure_advance: 0.0   # See tuning pressure advance doc
pressure_advance_smooth_time: 0.040

[tmc2209 extruder]
uart_pin: gpio9
tx_pin: gpio8
# MS2/AD1=0,MS1/AD0=0
uart_address: 0
interpolate: True
run_current: 0.650
hold_current: 0.500
sense_resistor: 0.220
stealthchop_threshold: 999999

[filament_switch_sensor runout_sensor]
switch_pin: ^gpio10
pause_on_runout: True

# [filament_motion_sensor smart_sensor]
# switch_pin: ^gpio10
# detection_length: 2.5

[heater_bed]
heater_pin: gpio23
sensor_type: EPCOS 100K B57560G104F
sensor_pin: gpio26
control: pid
pid_Kp: 54.027
pid_Ki: 0.770
pid_Kd: 948.182
min_temp: 0
max_temp: 130

[printer]
kinematics: corexy
max_velocity: 500
max_accel: 3000
max_z_velocity: 25
max_z_accel: 30
square_corner_velocity: 6.0

[heater_fan hotend_fan]
pin: gpio21
heater: extruder
heater_temp: 50.0

[fan]
pin: gpio20

#[heater_fan controller_fan]
#pin: gpio22
#heater: heater_bed
#heater_temp: 45.0

[temperature_sensor chamber]
sensor_type: EPCOS 100K B57560G104F
sensor_pin: gpio27
#min_temp:
#max_temp:

#[probe]
##	Inductive Probe - If you use this section , please comment the [bltouch] section
##	This probe is not used for Z height, only Quad Gantry Leveling
##	In Z+ position
##	If your probe is NC instead of NO, add change pin to ^PA3
#pin: ^gpio25
#x_offset: 0
#y_offset: 25.0
#z_offset: 0
#speed: 10.0
#samples: 3
#samples_result: median
#sample_retract_dist: 3.0
#samples_tolerance: 0.006
#samples_tolerance_retries: 3

#[bltouch]
#sensor_pin: gpio25
#control_pin: gpio13 # Reuse z endstop pin

#[neopixel board_rgb]
#pin: gpio29
#chain_count: 1
#color_order: GRB
#initial_RED: 0.3
#initial_GREEN: 0.3
#initial_BLUE: 0.3

[idle_timeout]
timeout: 1800

[safe_z_home]
home_xy_position: 120,120
speed: 50.0
z_hop: 5


# Tool to help adjust bed leveling screws. One may define a
# [bed_screws] config section to enable a BED_SCREWS_ADJUST g-code
# command.
[bed_screws]
screw1: 65,5
screw1_name: front screw
screw2: 10,110
screw2_name: back left
screw3: 120,110
screw3_name: back right


[gcode_macro PRINT_START]
#   Use PRINT_START for the slicer starting script - please customize for your slicer of choice
gcode:
    G28                            ; home all axes
    G1 Z20 F3000                   ; move nozzle away from bed
   
[gcode_macro PRINT_END]
#   Use PRINT_END for the slicer ending script - please customize for your slicer of choice
gcode:

    M400                           ; wait for buffer to clear
    G92 E0                         ; zero the extruder
    G1 E-4.0 F3600                 ; retract filament
    G91                            ; relative positioning

    #   Get Boundaries
    {% set max_x = printer.configfile.config["stepper_x"]["position_max"]|float %}
    {% set max_y = printer.configfile.config["stepper_y"]["position_max"]|float %}
    {% set max_z = printer.configfile.config["stepper_z"]["position_max"]|float %}

    #   Check end position to determine safe direction to move
    {% if printer.toolhead.position.x < (max_x - 20) %}
        {% set x_safe = 20.0 %}
    {% else %}
        {% set x_safe = -20.0 %}
    {% endif %}

    {% if printer.toolhead.position.y < (max_y - 20) %}
        {% set y_safe = 20.0 %}
    {% else %}
        {% set y_safe = -20.0 %}
    {% endif %}

    {% if printer.toolhead.position.z < (max_z - 2) %}
        {% set z_safe = 2.0 %}
    {% else %}
        {% set z_safe = max_z - printer.toolhead.position.z %}
    {% endif %}

    G0 Z{z_safe} F3600    ; move nozzle up
    G0 X{x_safe} Y{y_safe} F20000    ; move nozzle to remove stringing
    TURN_OFF_HEATERS
    M107                           ; turn off fan
    G90                            ; absolute positioning
    G0 X60 Y{max_y} F3600          ; park nozzle at rear
	
[gcode_macro LOAD_FILAMENT]
gcode:
   M83                            ; set extruder to relative
   G1 E30 F300                    ; load
   G1 E15 F150                    ; prime nozzle with filament
   M82                            ; set extruder to absolute
    
[gcode_macro UNLOAD_FILAMENT]
gcode:
   M83                            ; set extruder to relative
   G1 E10 F300                    ; extrude a little to soften tip
   G1 E-40 F1800                  ; retract some, but not too much or it will jam
   M82                            ; set extruder to absolute

#[include v0_display.cfg]
#[include bedScrewMenu.cfg]

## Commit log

2022-07-28 Correct printer.cfg fan pin
    [printer.cfg]
2023-11-04 Correct printer.cfg TMC sense resistor
    [printer.cfg]
